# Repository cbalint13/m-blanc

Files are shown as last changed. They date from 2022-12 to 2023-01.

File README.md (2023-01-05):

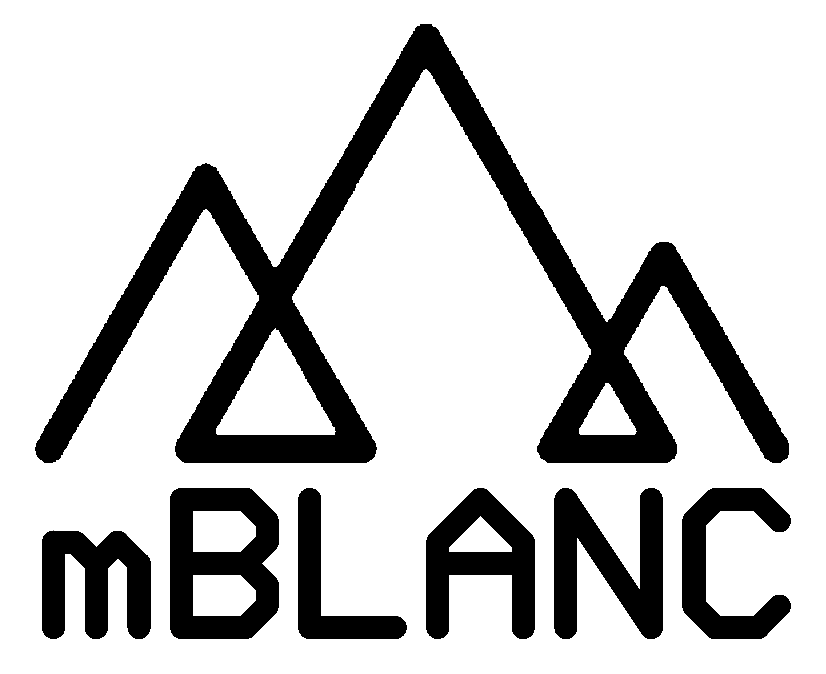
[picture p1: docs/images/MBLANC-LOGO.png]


**m**ini **B**oard **La**b a**n**d **C**ompanion

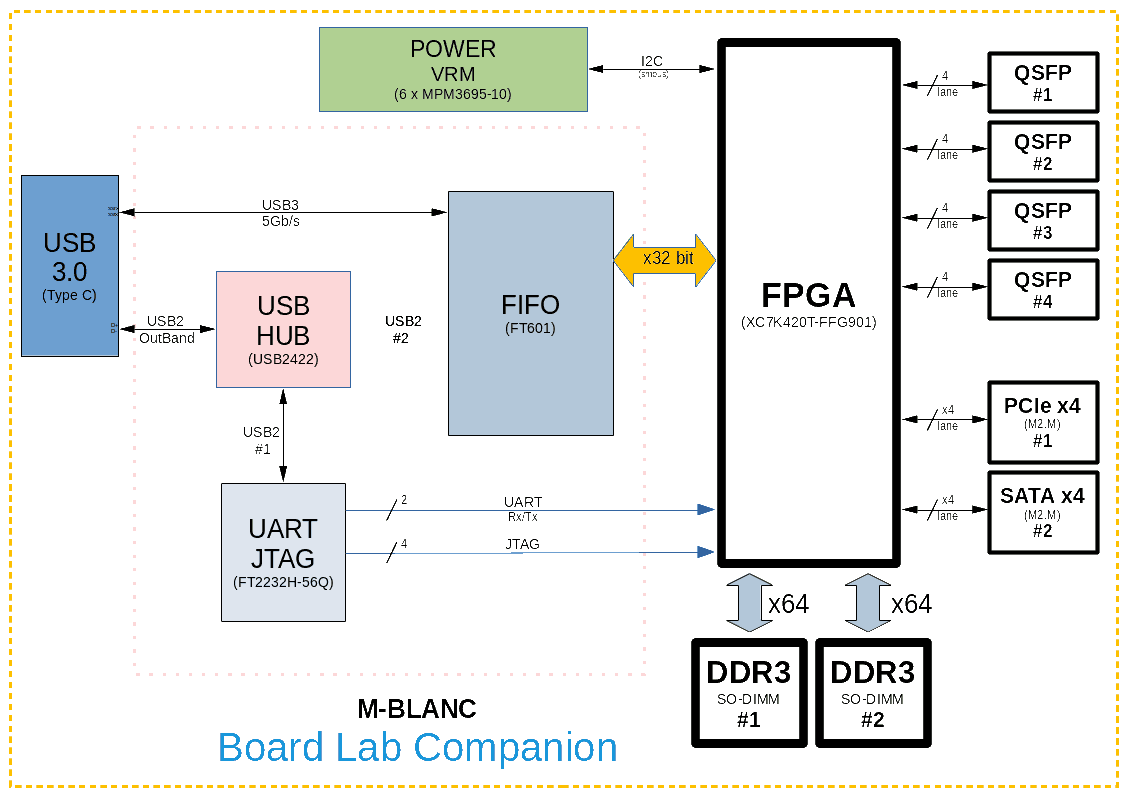
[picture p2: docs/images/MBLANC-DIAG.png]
DIAG


## Description

  With the rising of high quality opensource tools for FPGAs new opportunities are emerging to discover and build better digital architectures.
  This board is intended to explore & research the world of modern digital systems that requires large memory bus and high-speed peripherials.

## Specs:

* Large **xc7k420t** **FPGA** design space
* Two **DDR3 SO-DIMM** sockets having **128 (2 x 64) bits** wide access
* USB3 **5Gbps/s** data access over **x32** wide independent FIFO
* USB2 outband (same usb port) permanent **JTAG** and **UART** independent access
* Two  **M.2** (M-key), 4 x SERDes lanes each, PCIe & SATA mappable
* Four **QSFP** sockets 4 x SERDes lanes each, with up to 10Gb/s line rates

Can be used in any USB port right from the tips of fingers, no cables, no wires but full control.

| TOP | BOTTOM |
| --- | --- |
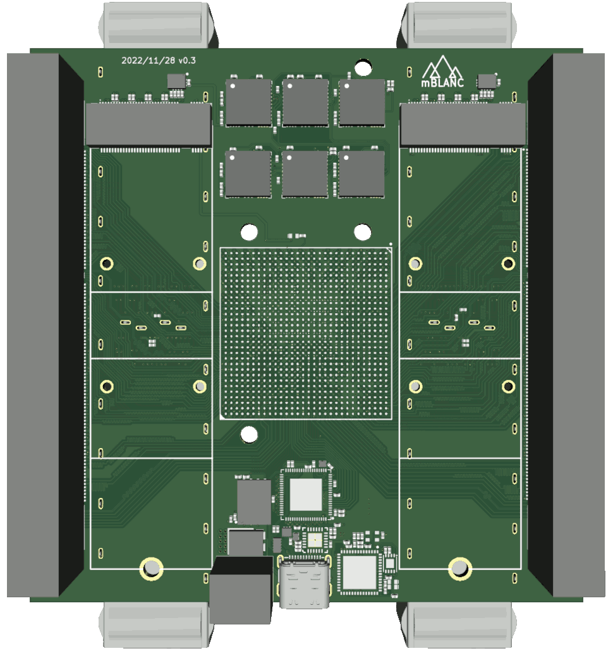
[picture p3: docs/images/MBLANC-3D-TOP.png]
TOP
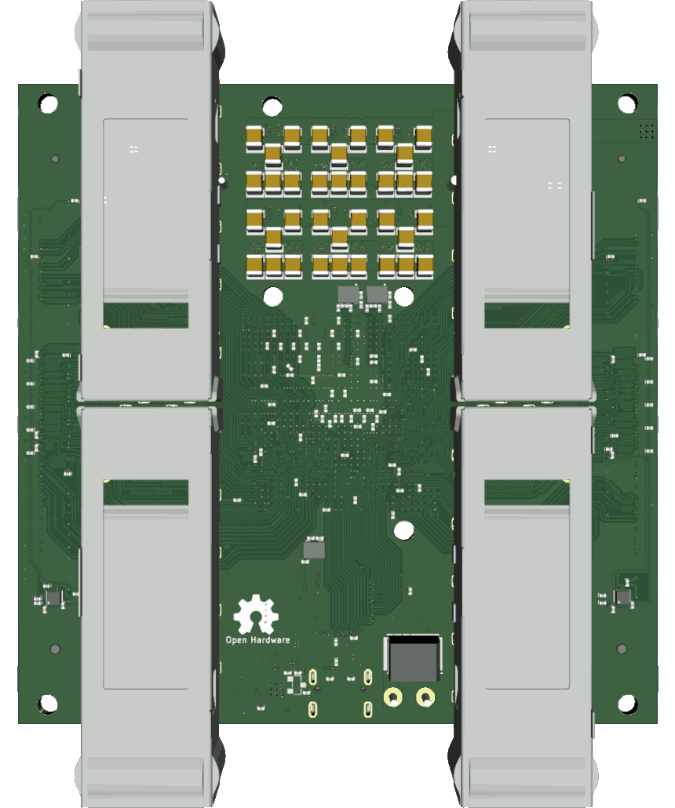
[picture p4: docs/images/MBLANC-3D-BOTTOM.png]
BOTTOM
|||

## Progress:

* ```17-Aug-2021``` Initial design and PCB prototype is done.
* ```22-Nov-2022``` Updated design having first PCB samples.

## Project files

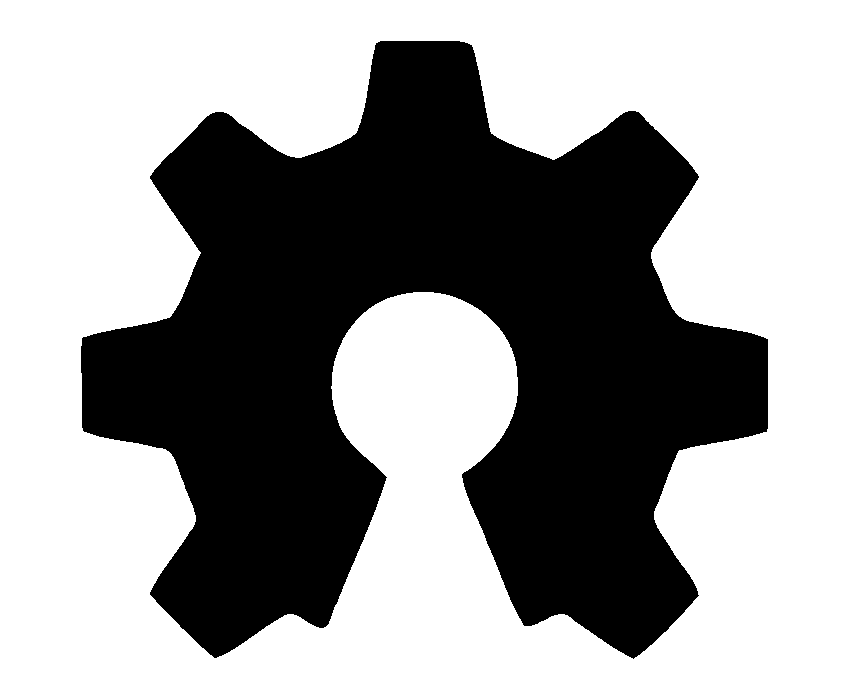
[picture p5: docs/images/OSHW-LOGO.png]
* Open Source Hardware 
* Check [schematic](hardware/m-BLANC-v0_3.pdf) available as quick readable document.
* See the [design files](hardware) available for Altium ®, CircuitMaker ®, KiCAD and Gerber format.

## PCB views

| Layer | Desc | Image | Layer | Desc | Image |
| --- | ---- | --- | --- | ---- | --- |
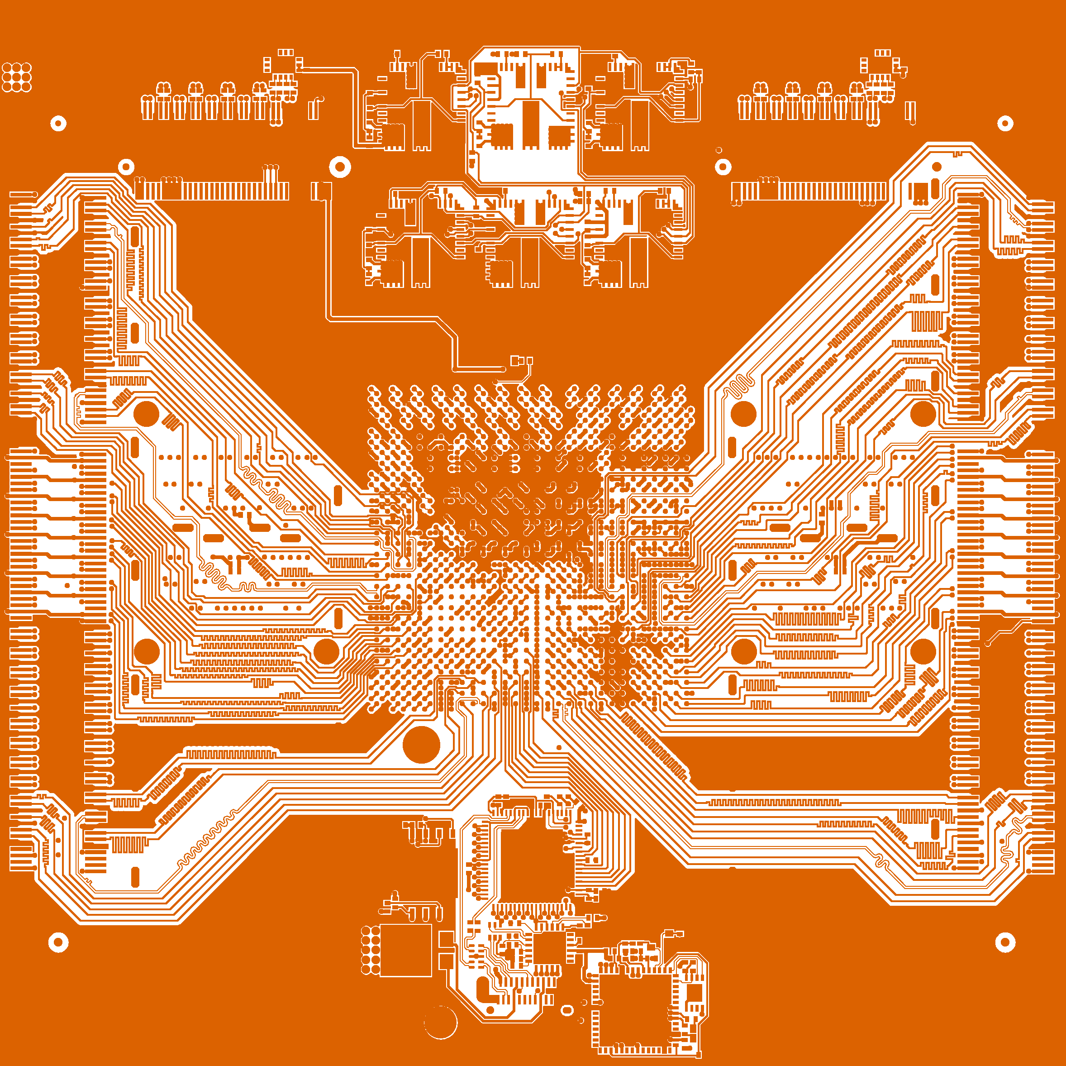
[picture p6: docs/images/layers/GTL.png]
GTL
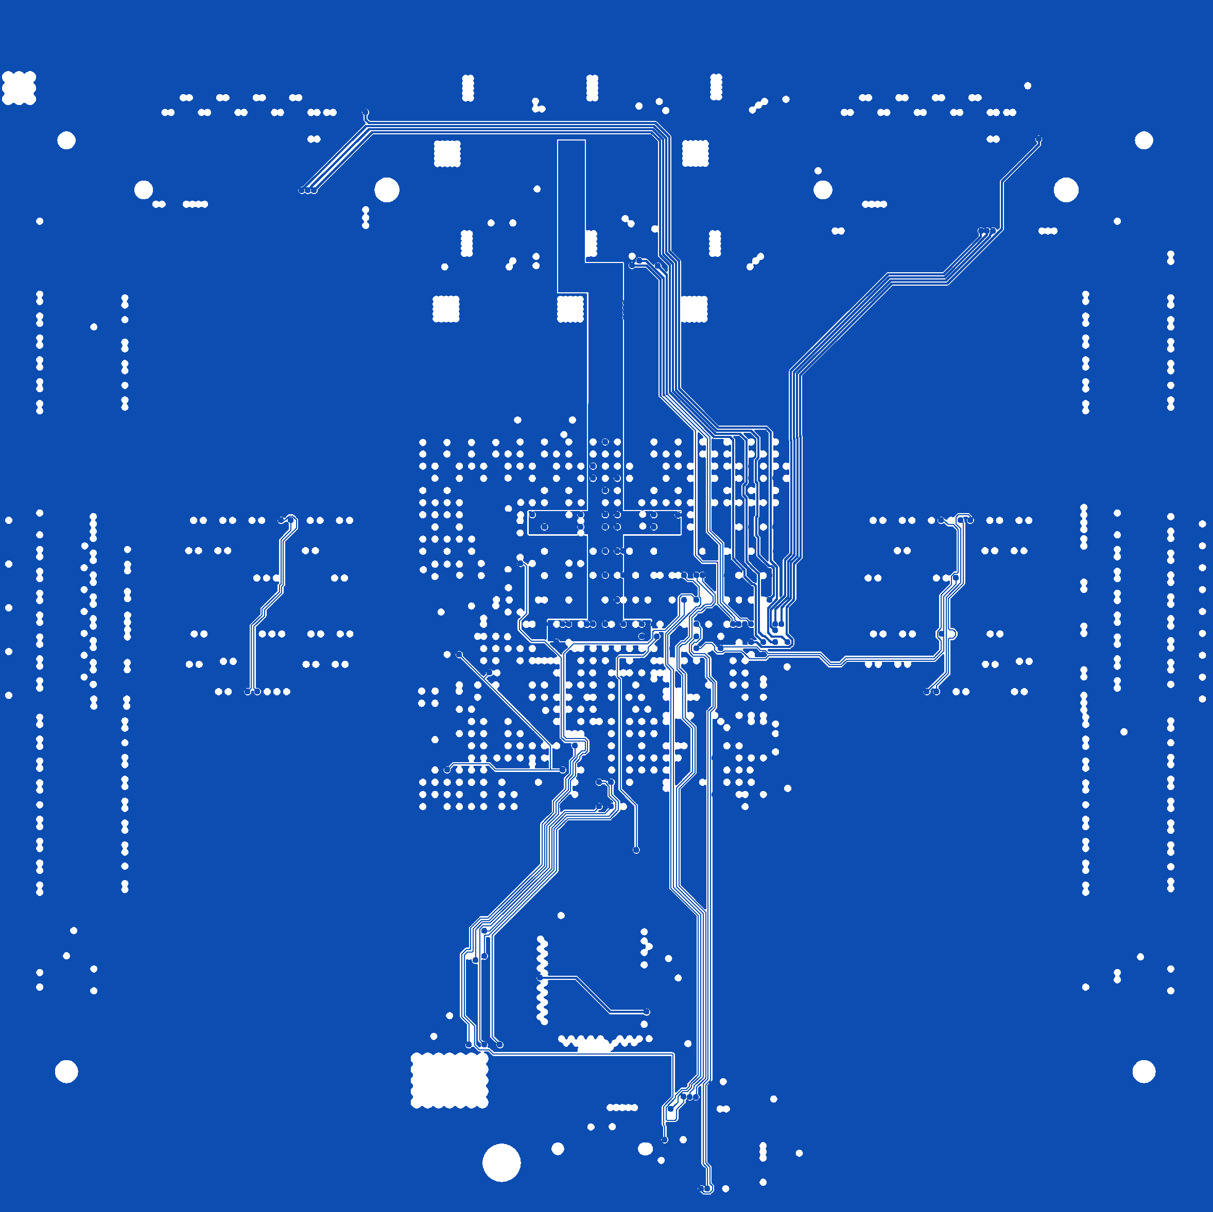
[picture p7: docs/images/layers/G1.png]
G1
|**Top** |Signal||**Inner1**|GND |  |
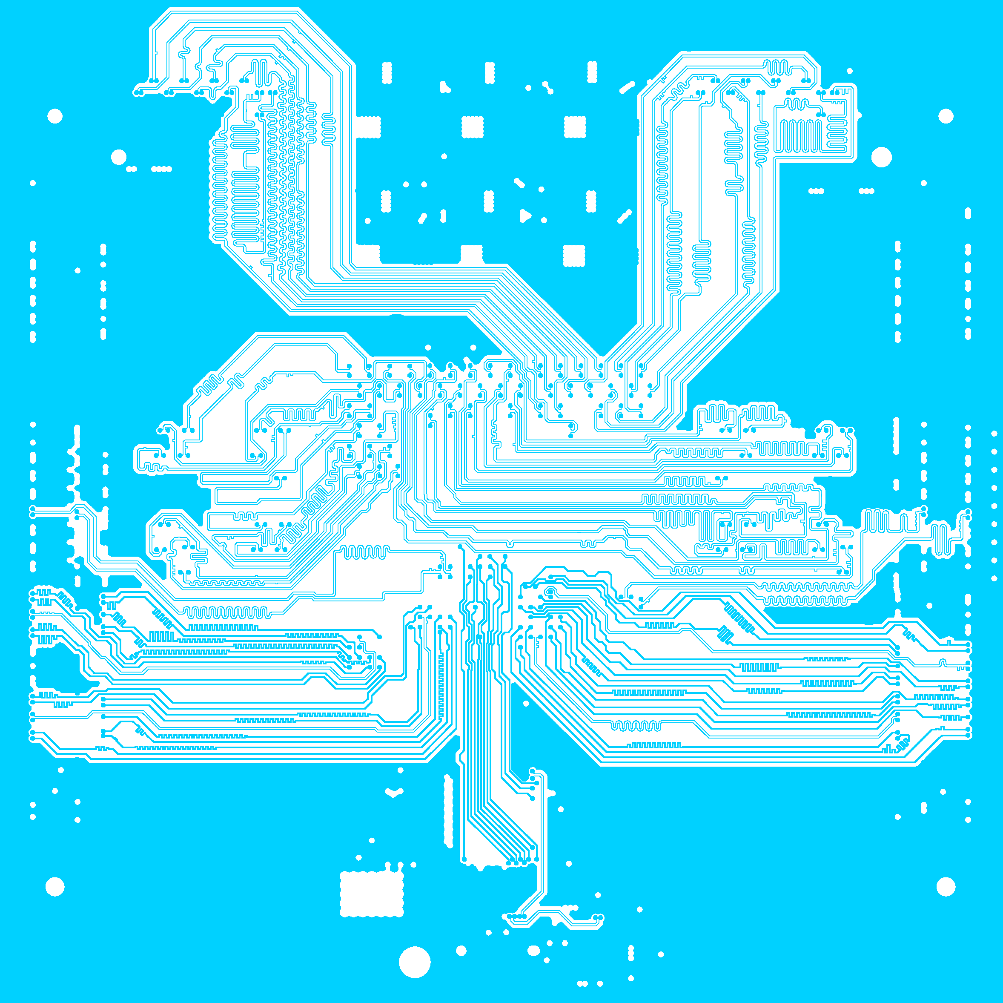
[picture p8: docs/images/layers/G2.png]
G2
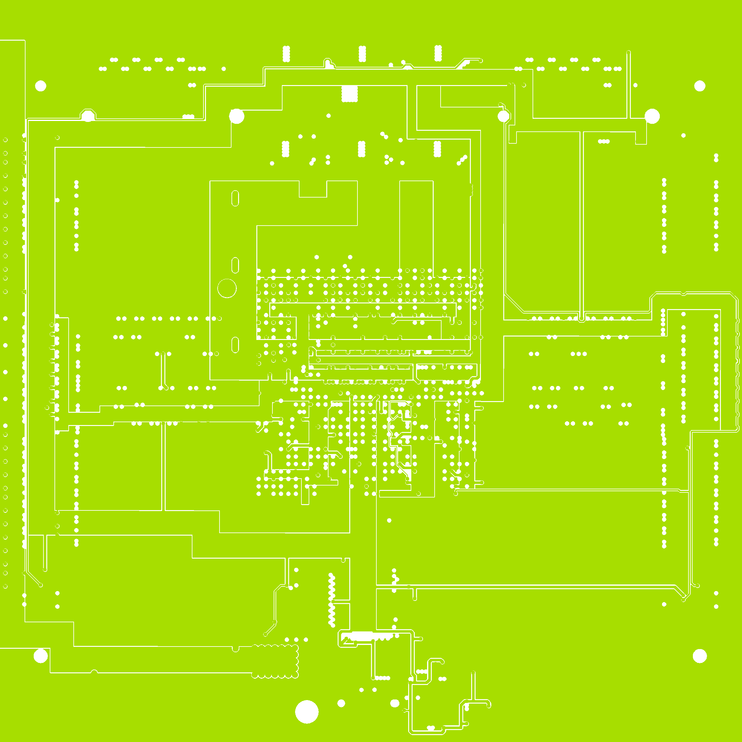
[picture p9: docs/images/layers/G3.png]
G3
|**Inner2**|Signal|  |**Inner3**|Power |  |
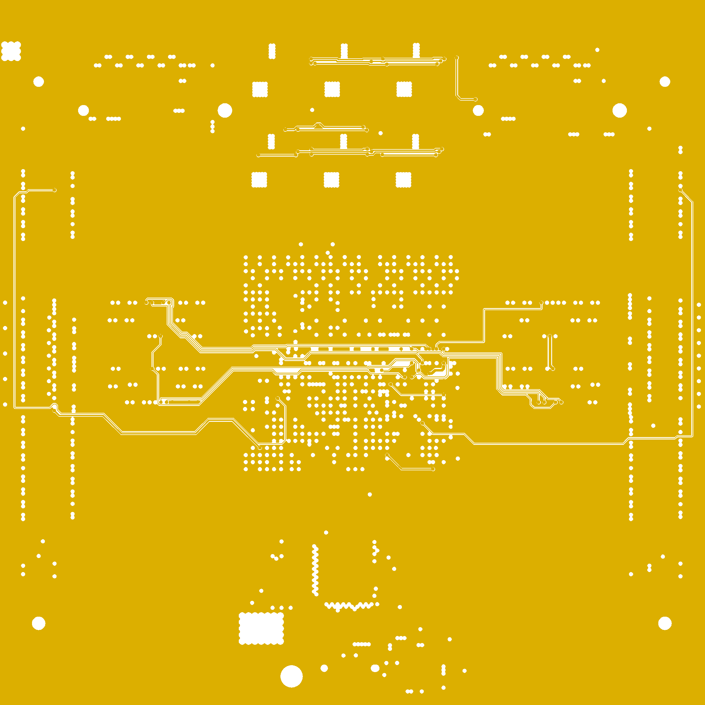
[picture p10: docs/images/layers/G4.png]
G4
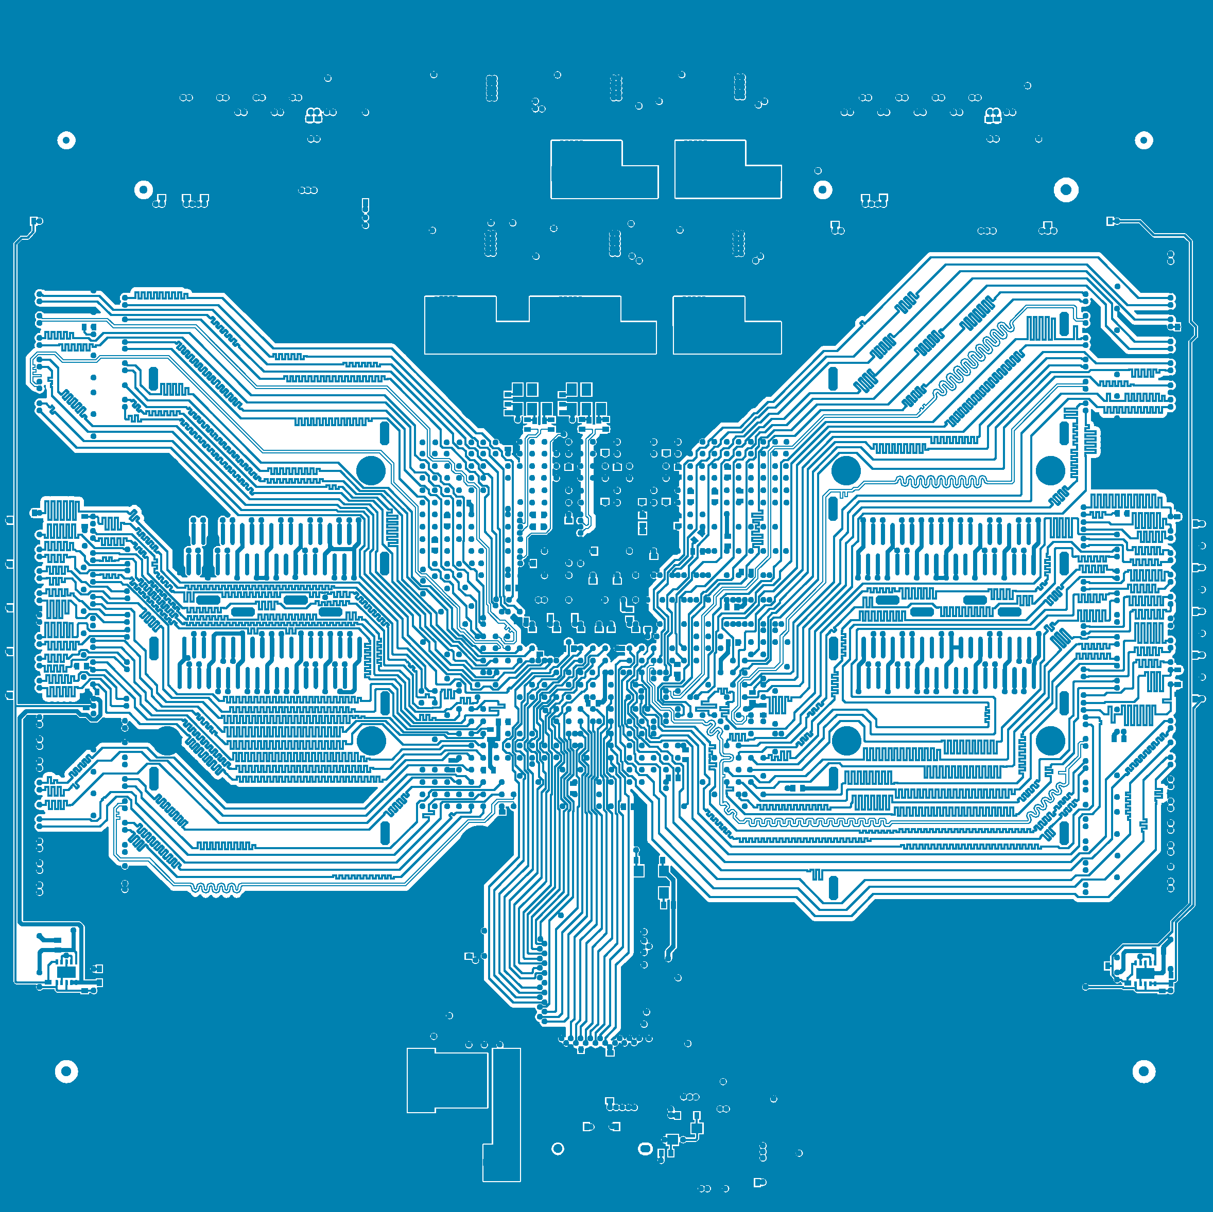
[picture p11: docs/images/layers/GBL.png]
GBL
|**Inner4**|GND |  |**Bottom**|Signal||

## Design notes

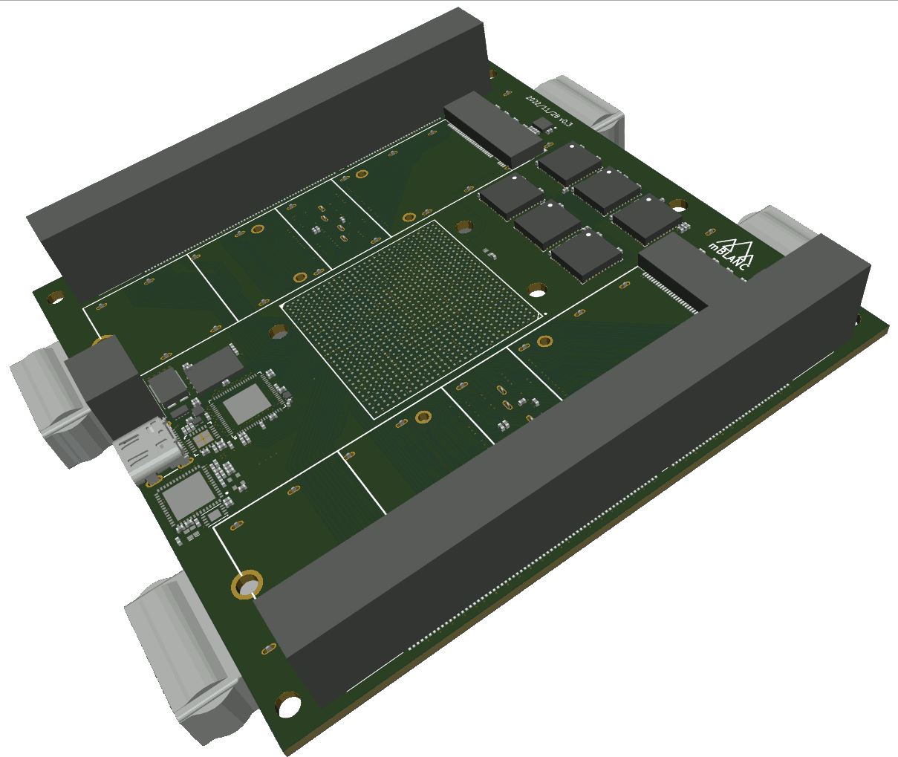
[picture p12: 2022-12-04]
docs/images/MBLANC-3D.png

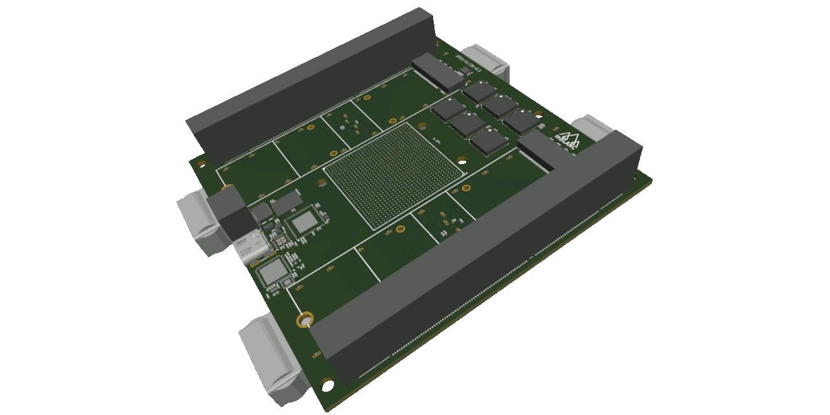
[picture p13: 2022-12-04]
docs/images/MBLANC-3D-preview.png

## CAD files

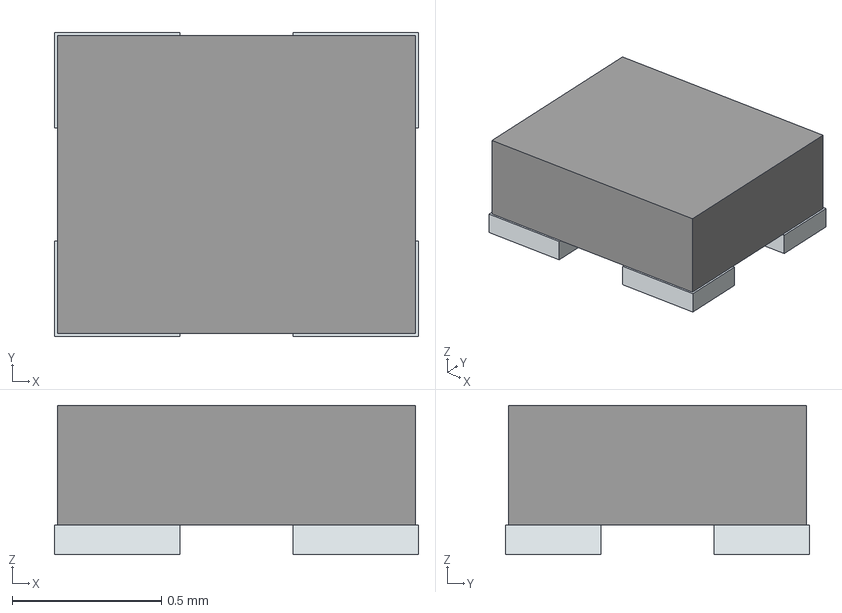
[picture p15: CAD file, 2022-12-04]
hardware/mblanc_v0.3/kicad/m-blanc/3d-models/ABM13W-52.0000MHZ-5-B2G-T5.stp
1.22 x 1.02 x 0.5 mm
('pin',_'1')
('pin',_'2')
('pin',_'3')
('pin',_'4')

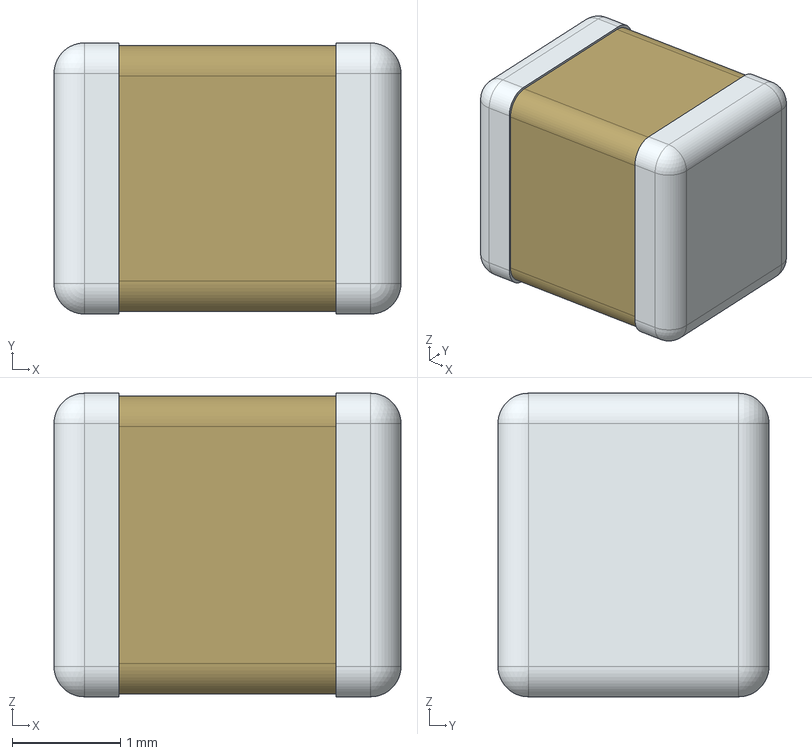
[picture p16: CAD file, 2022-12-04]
hardware/mblanc_v0.3/kicad/m-blanc/3d-models/JMK325ABJ107MM-P.stp
3.20 x 2.50 x 2.80 mm

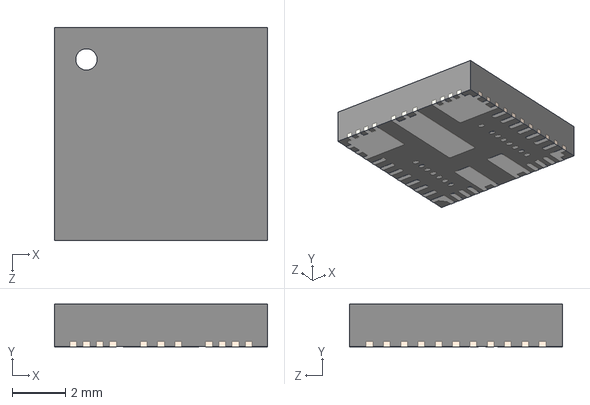
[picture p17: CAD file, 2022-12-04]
hardware/mblanc_v0.3/kicad/m-blanc/3d-models/MPM3695-10.STEP
8.00 x 1.61 x 8.00 mm

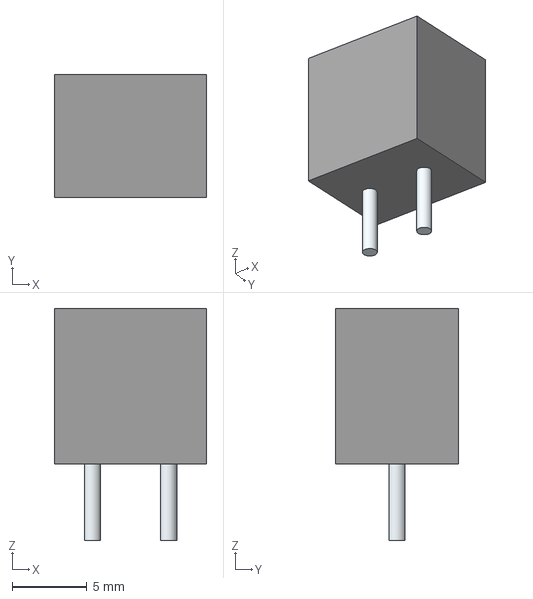
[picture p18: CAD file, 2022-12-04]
hardware/mblanc_v0.3/kicad/m-blanc/3d-models/TB006-508-02BE.stp
10.2 x 8.20 x 15.5 mm
Leads x 2

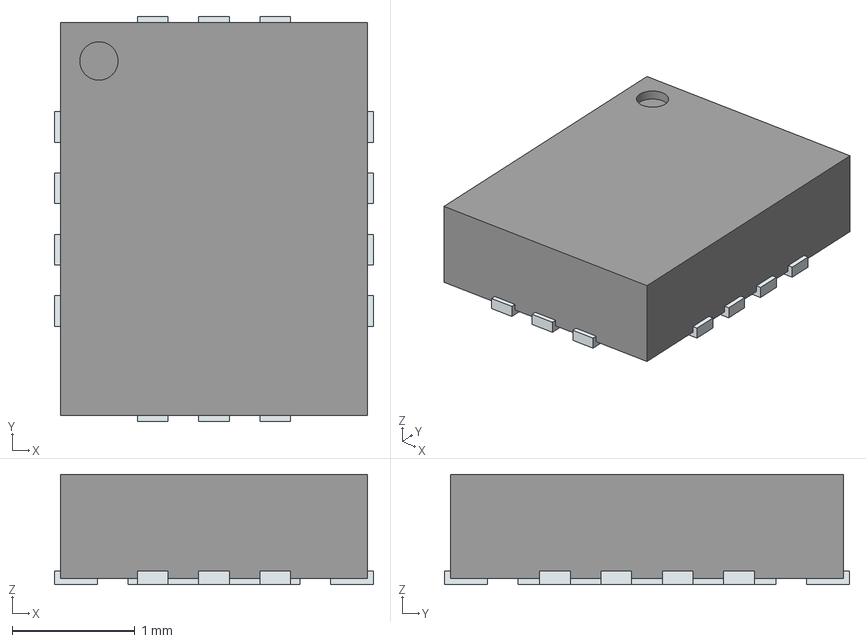
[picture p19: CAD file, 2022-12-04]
hardware/mblanc_v0.3/kicad/m-blanc/3d-models/DSC557-0344FI0.stp
2.60 x 3.30 x 0.9 mm
ThermalPin
PinsArrayLR
PinsArrayTB

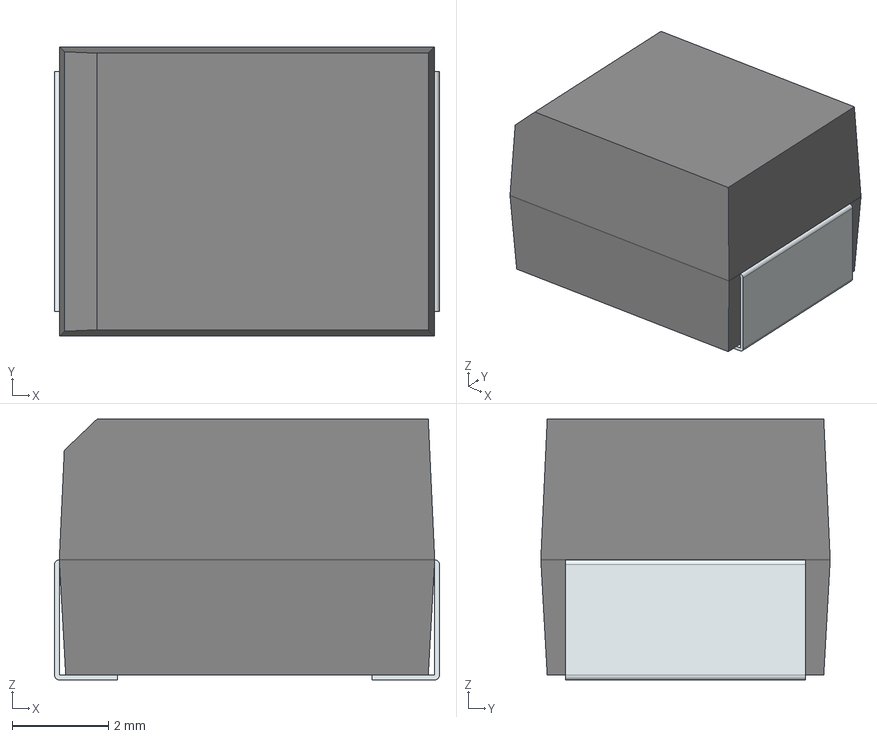
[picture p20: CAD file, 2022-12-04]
hardware/mblanc_v0.3/kicad/m-blanc/3d-models/SK106-TP.stp
8.02 x 6.03 x 5.43 mm
FilletPin1
FilletPin2

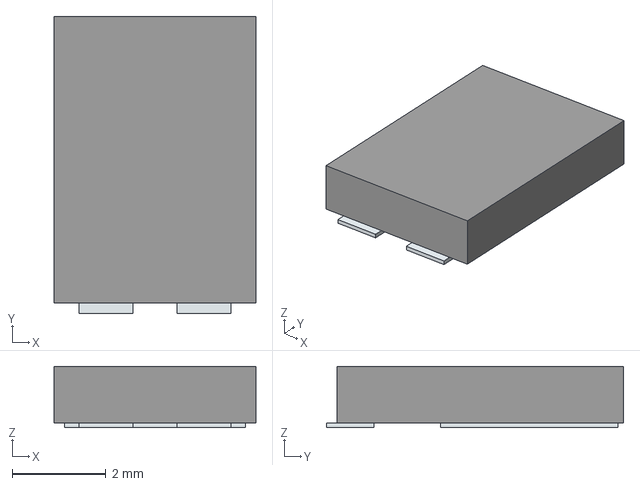
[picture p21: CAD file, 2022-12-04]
hardware/mblanc_v0.3/kicad/m-blanc/3d-models/V10P20-M3_86A.stp
4.30 x 6.32 x 1.30 mm
Pins

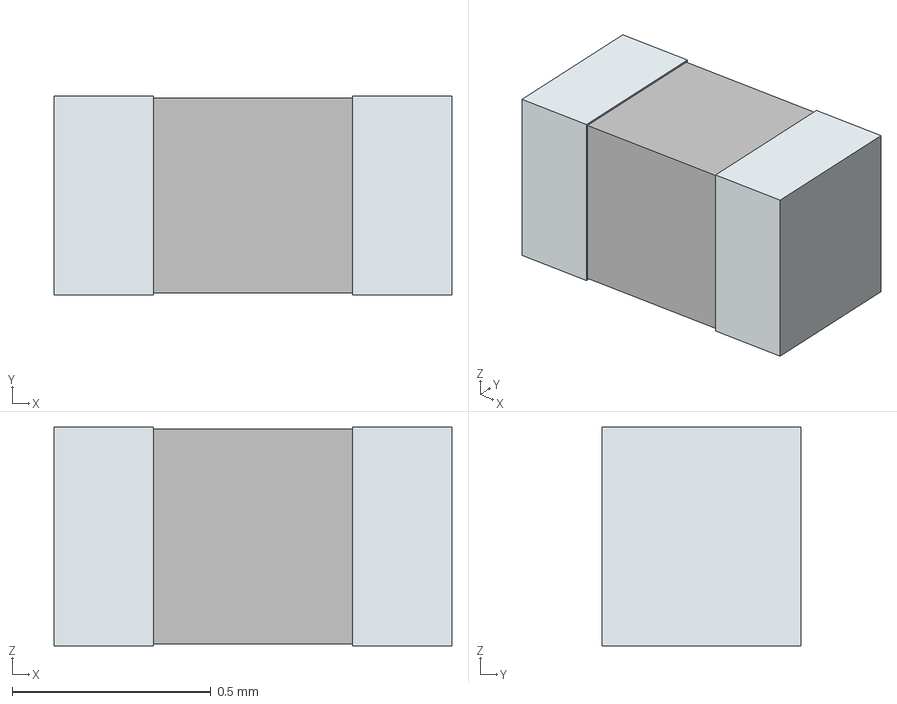
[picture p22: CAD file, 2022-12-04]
hardware/mblanc_v0.3/kicad/m-blanc/3d-models/BLM15AX601SN1D.stp
1.00 x 0.5 x 0.55 mm
term1
term2

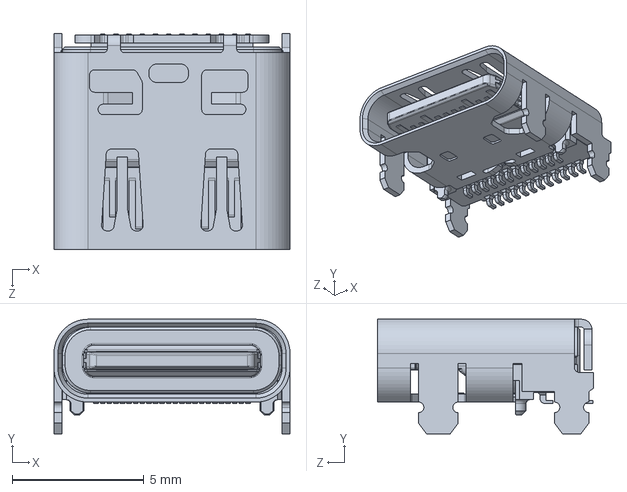
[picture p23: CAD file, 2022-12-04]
hardware/mblanc_v0.3/kicad/m-blanc/3d-models/K3D-DX07S024JA2-V1_JAE_Proprietary.STEP
8.94 x 4.34 x 8.17 mm

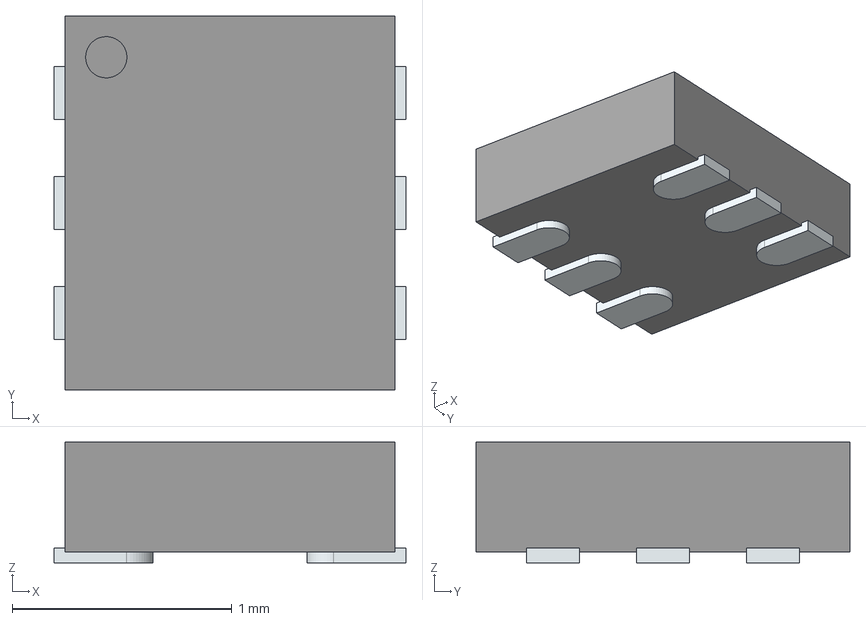
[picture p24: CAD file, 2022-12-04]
hardware/mblanc_v0.3/kicad/m-blanc/3d-models/ECMF02-2AMX6.stp
1.60 x 1.70 x 0.55 mm
PinsArrayLR

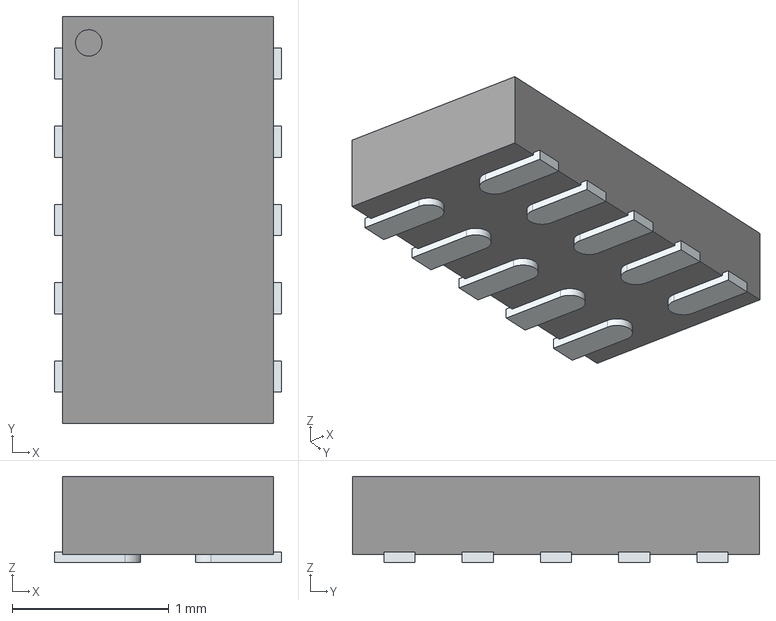
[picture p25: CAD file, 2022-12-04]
hardware/mblanc_v0.3/kicad/m-blanc/3d-models/ECMF04-4HSWM10.stp
1.45 x 2.60 x 0.55 mm
PinsArrayLR

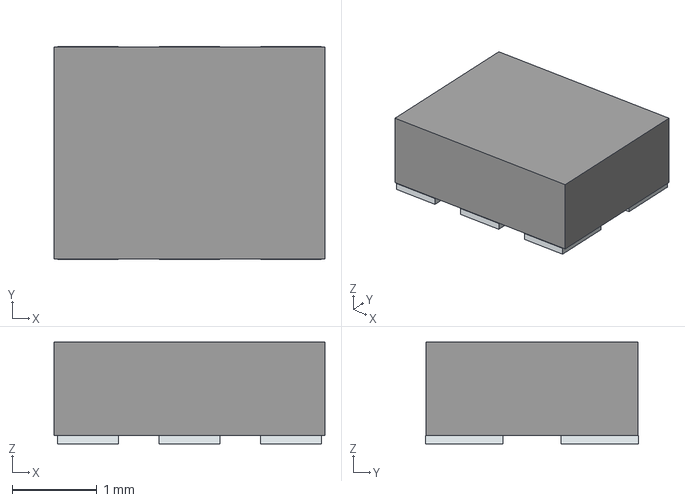
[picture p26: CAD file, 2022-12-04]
hardware/mblanc_v0.3/kicad/m-blanc/3d-models/AX3DAF1-100.0000.stp
3.20 x 2.52 x 1.20 mm
Pins

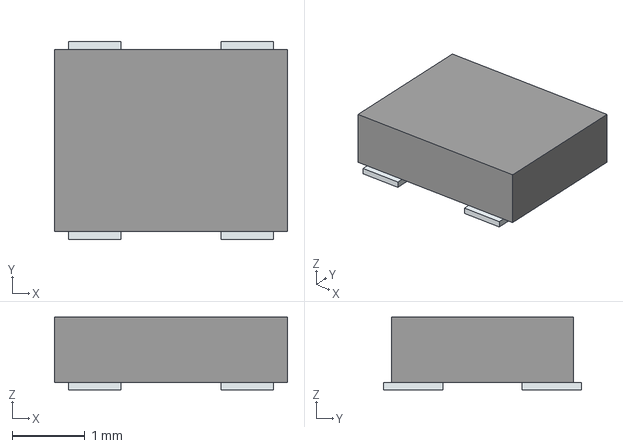
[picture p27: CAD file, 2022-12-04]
hardware/mblanc_v0.3/kicad/m-blanc/3d-models/ASEM1-100.000MHZ-L-C-T.stp
3.20 x 2.72 x 1.00 mm
Pins

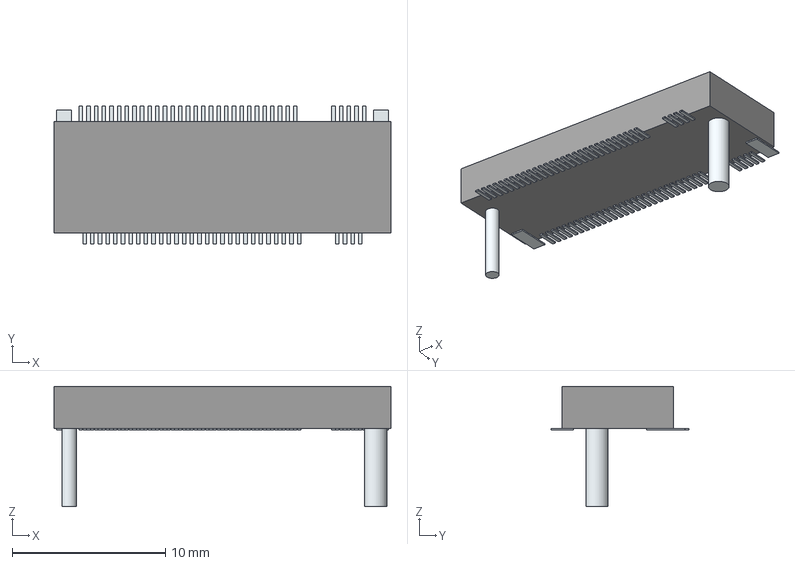
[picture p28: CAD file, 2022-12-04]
hardware/mblanc_v0.3/kicad/m-blanc/3d-models/MDT275M02001.stp
22.0 x 9.04 x 7.85 mm
('pin',_'1')
('pin',_'2')
('pin',_'3')
('pin',_'4')
('pin',_'5')
('pin',_'6')
('pin',_'7')
('pin',_'8')
('pin',_'9')
('pin',_'10')
('pin',_'11')
('pin',_'12')
('pin',_'13')
('pin',_'14')
('pin',_'15')
('pin',_'16')
('pin',_'17')
('pin',_'18')
('pin',_'19')
('pin',_'20')
('pin',_'21')
('pin',_'22')
('pin',_'23')
('pin',_'24')
('pin',_'25')
('pin',_'26')
('pin',_'27')
('pin',_'28')
('pin',_'29')
('pin',_'30')
('pin',_'31')
('pin',_'32')
('pin',_'33')
('pin',_'34')
('pin',_'35')
('pin',_'36')
('pin',_'37')
('pin',_'38')
('pin',_'39')
('pin',_'40')
('pin',_'41')
('pin',_'42')
('pin',_'43')
('pin',_'44')
('pin',_'45')
('pin',_'46')
('pin',_'47')
('pin',_'48')
('pin',_'49')
('pin',_'50')
('pin',_'51')
('pin',_'52')
('pin',_'53')
('pin',_'54')
('pin',_'55')
('pin',_'56')
('pin',_'57')
('pin',_'58')
('pin',_'59')
('pin',_'60')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

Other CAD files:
hardware/mblanc_v0.3/kicad/m-blanc/3d-models/S25HL512TFANHI010.stp
hardware/mblanc_v0.3/kicad/m-blanc/3d-models/step_temp.STEP
hardware/mblanc_v0.3/kicad/m-blanc/3d-models/74750-0021.stp
hardware/mblanc_v0.3/kicad/m-blanc/3d-models/296409204003856+.stp

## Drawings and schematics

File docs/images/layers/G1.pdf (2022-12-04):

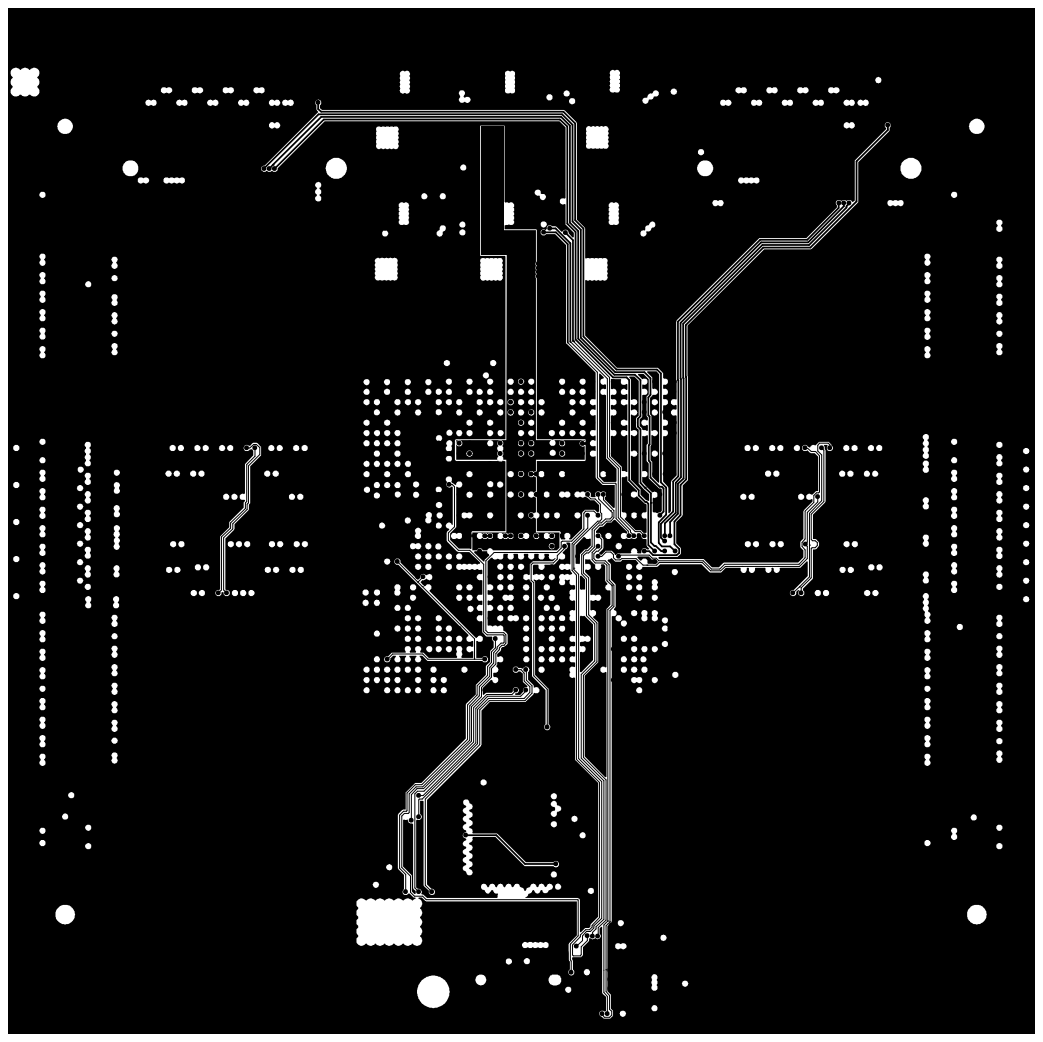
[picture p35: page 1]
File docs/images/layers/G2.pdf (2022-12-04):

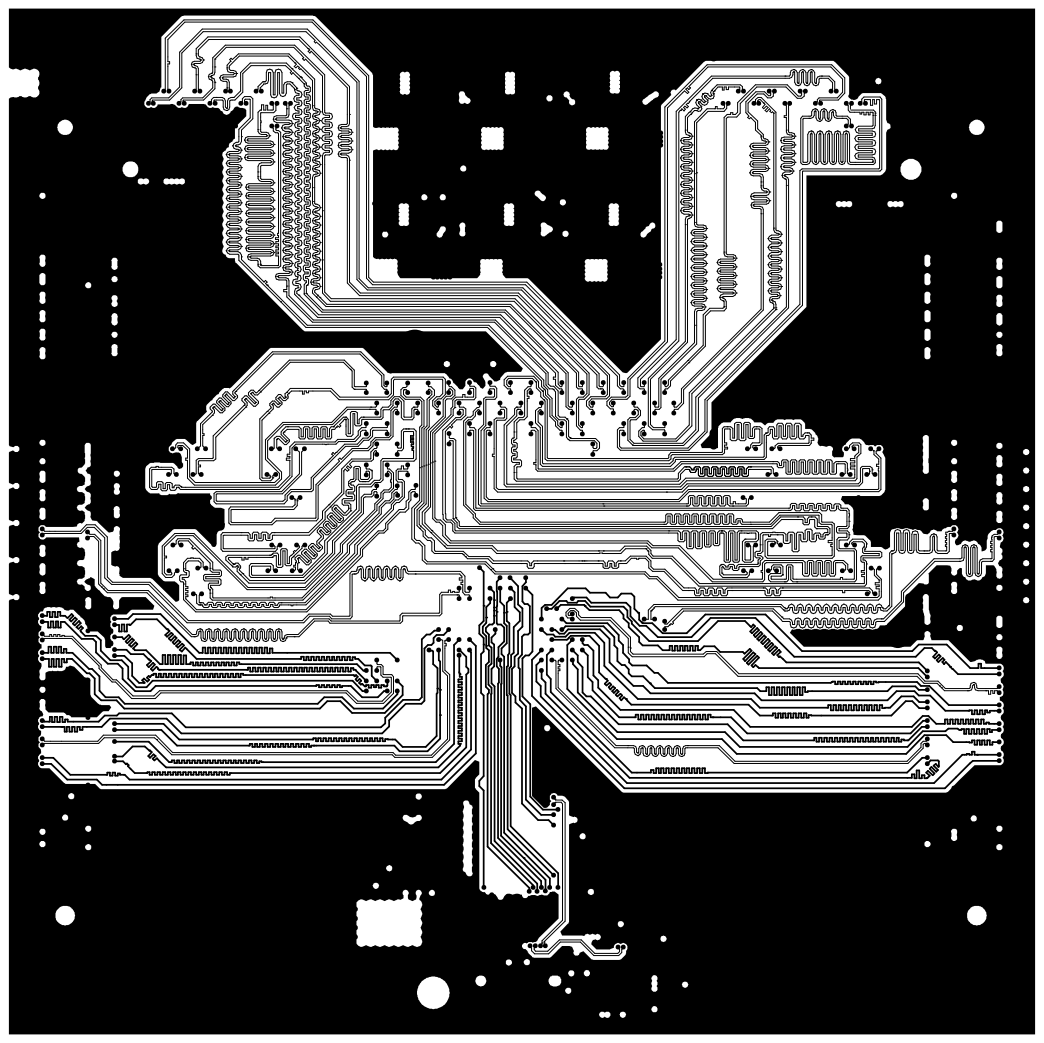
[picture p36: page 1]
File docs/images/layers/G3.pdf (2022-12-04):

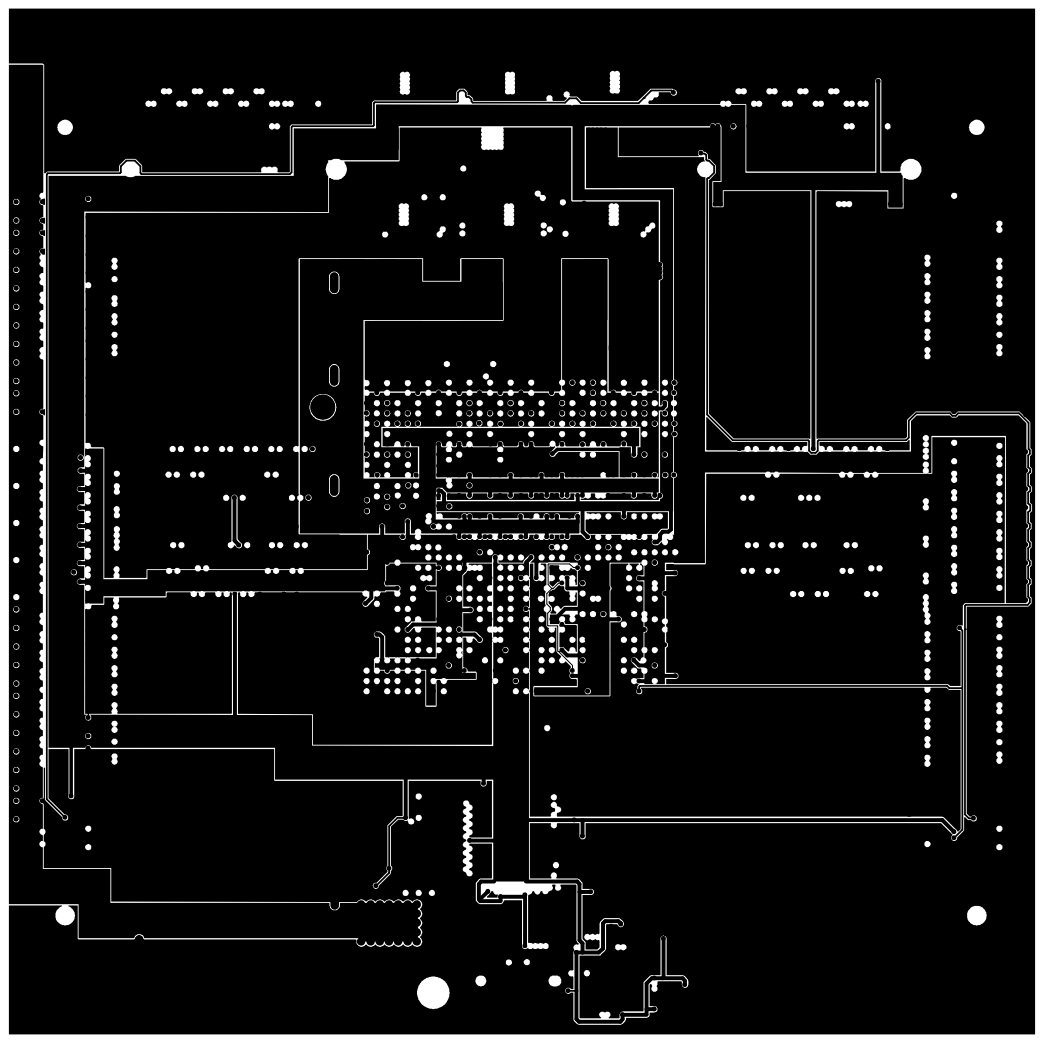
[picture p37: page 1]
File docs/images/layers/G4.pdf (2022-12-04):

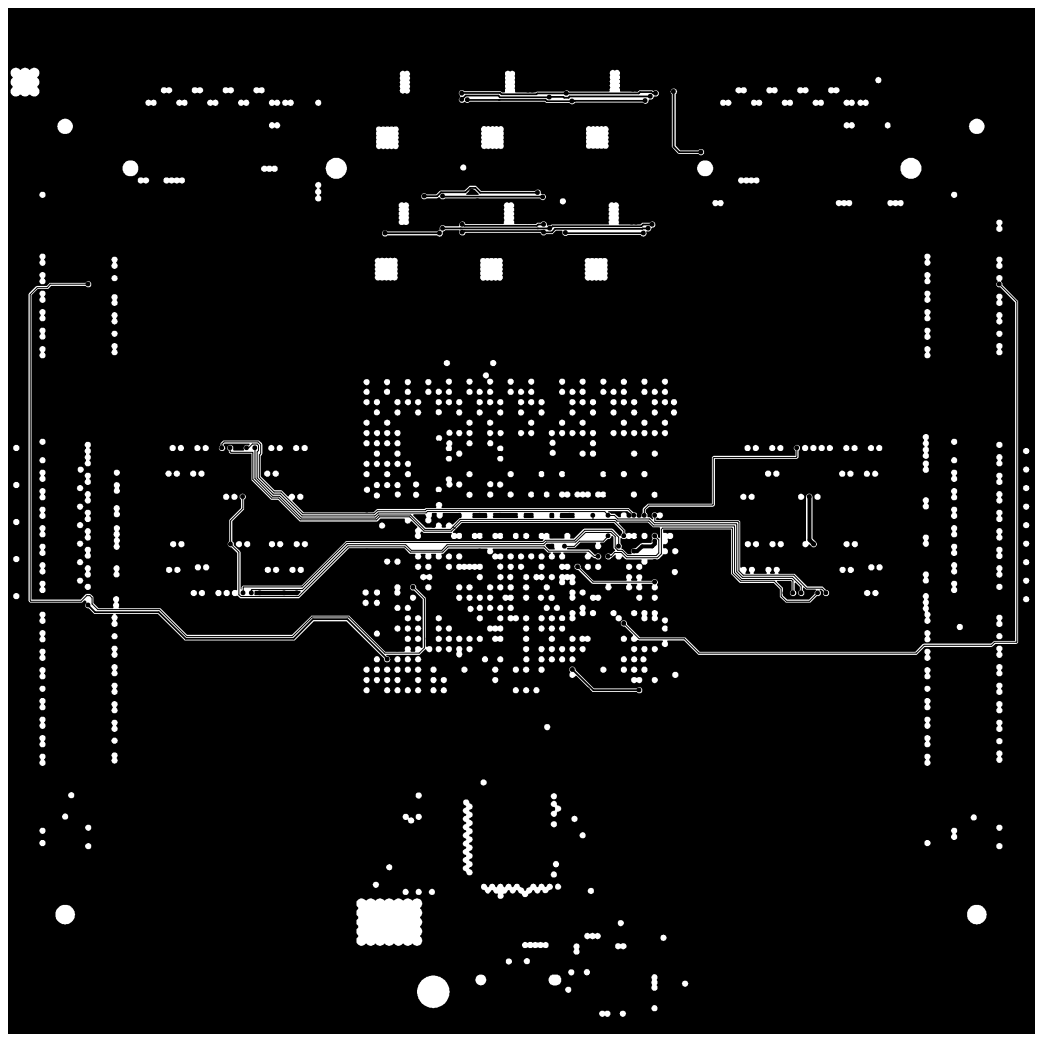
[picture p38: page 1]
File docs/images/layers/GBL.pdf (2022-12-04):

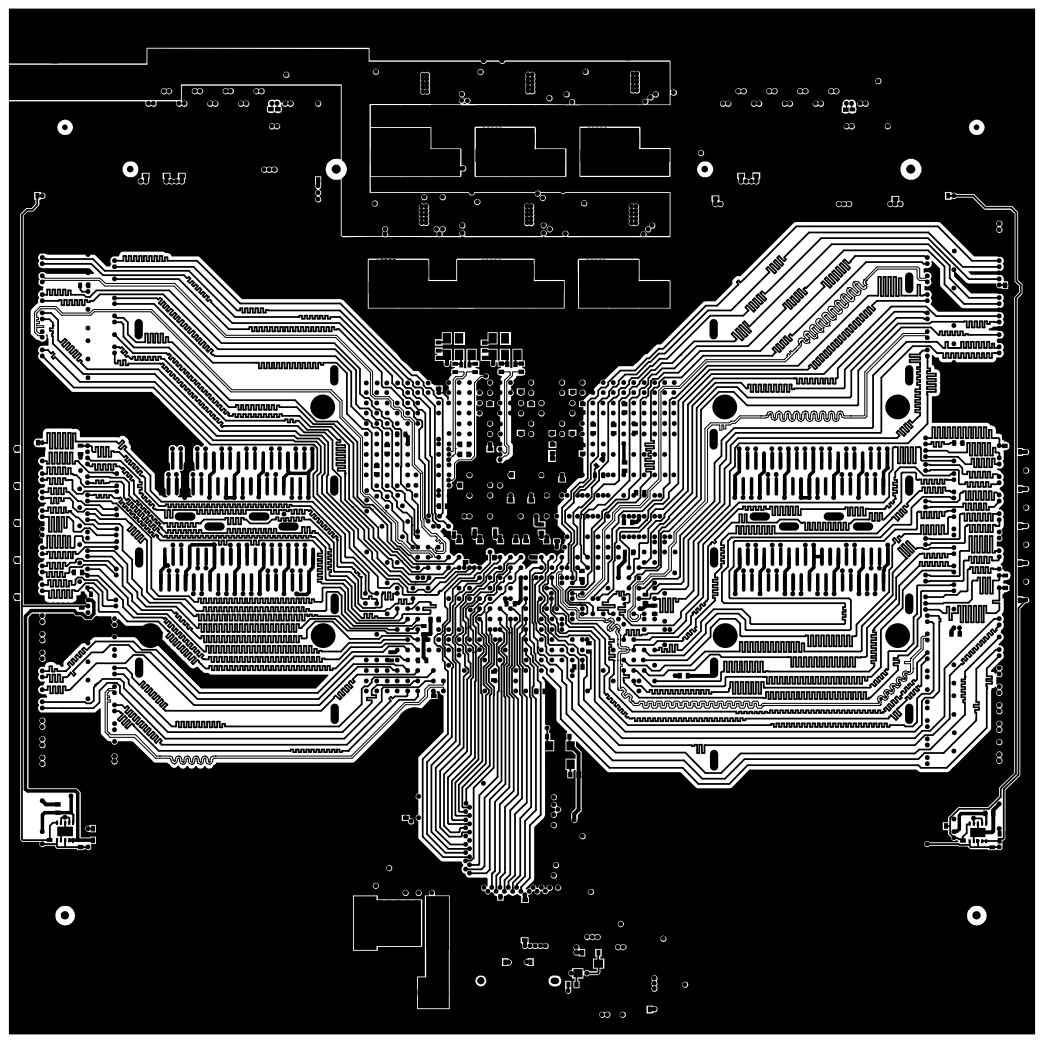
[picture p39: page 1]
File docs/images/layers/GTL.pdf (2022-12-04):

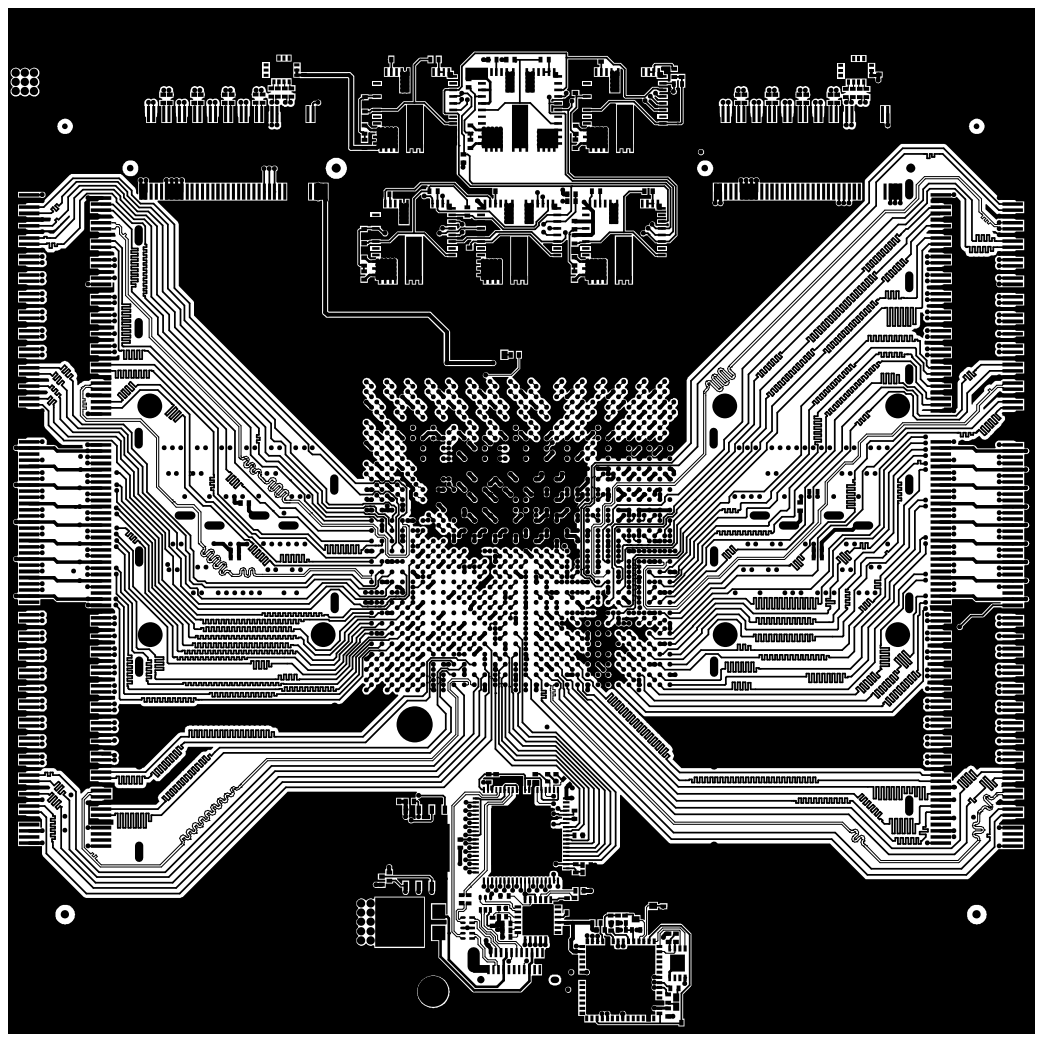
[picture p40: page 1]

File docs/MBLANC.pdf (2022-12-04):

## QSFP

## QSFP

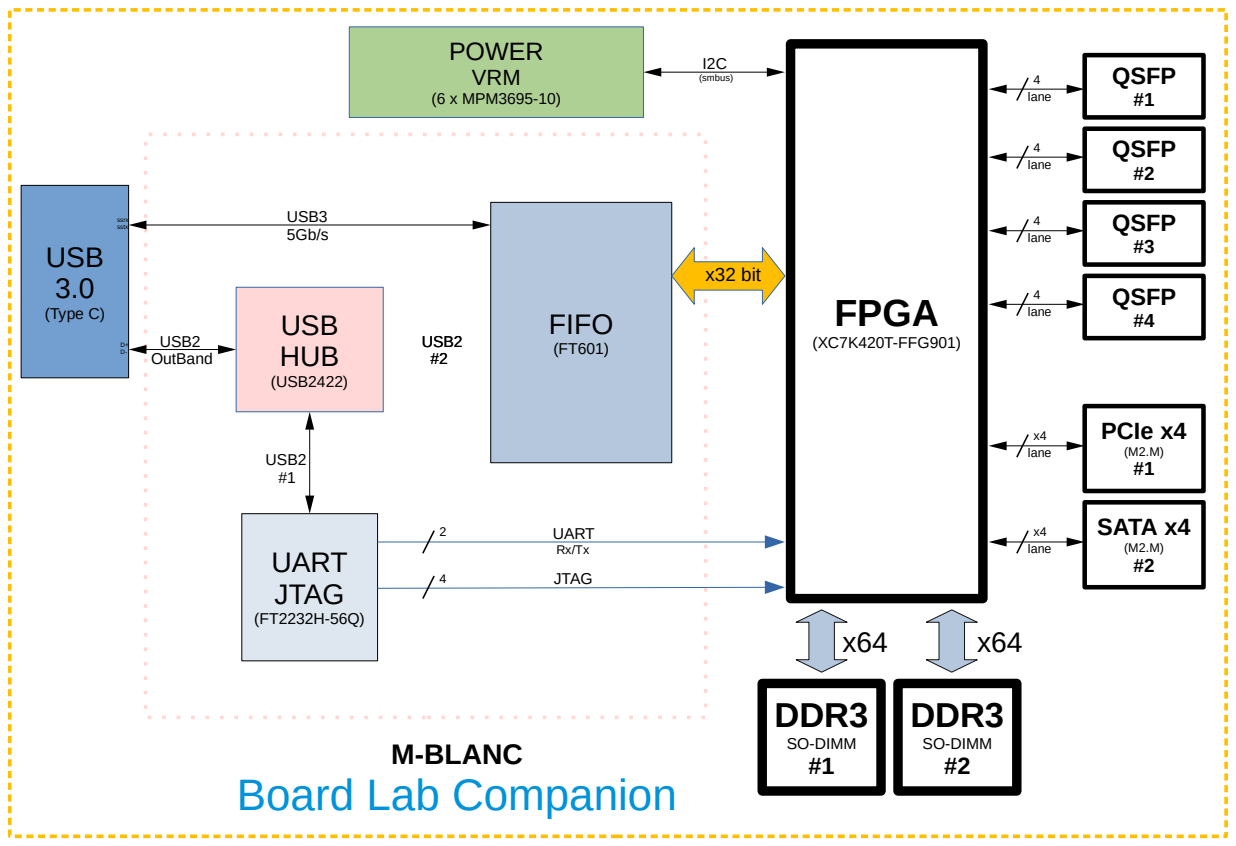
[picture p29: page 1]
USB; (Type C); HUB; (USB2422); FIFO; FPGA; (XC7K420T-FFG901); UART; JTAG; USB3; USB2; OutBand; x32 bit; ssrx sstx; M-BLANC; DDR3; SO-DIMM #1; SO-DIMM #2; PCIe x4; QSFP; SATA x4; lane; POWER; VRM; (6 x MPM3695-10); (smbus)

Board Lab Companion

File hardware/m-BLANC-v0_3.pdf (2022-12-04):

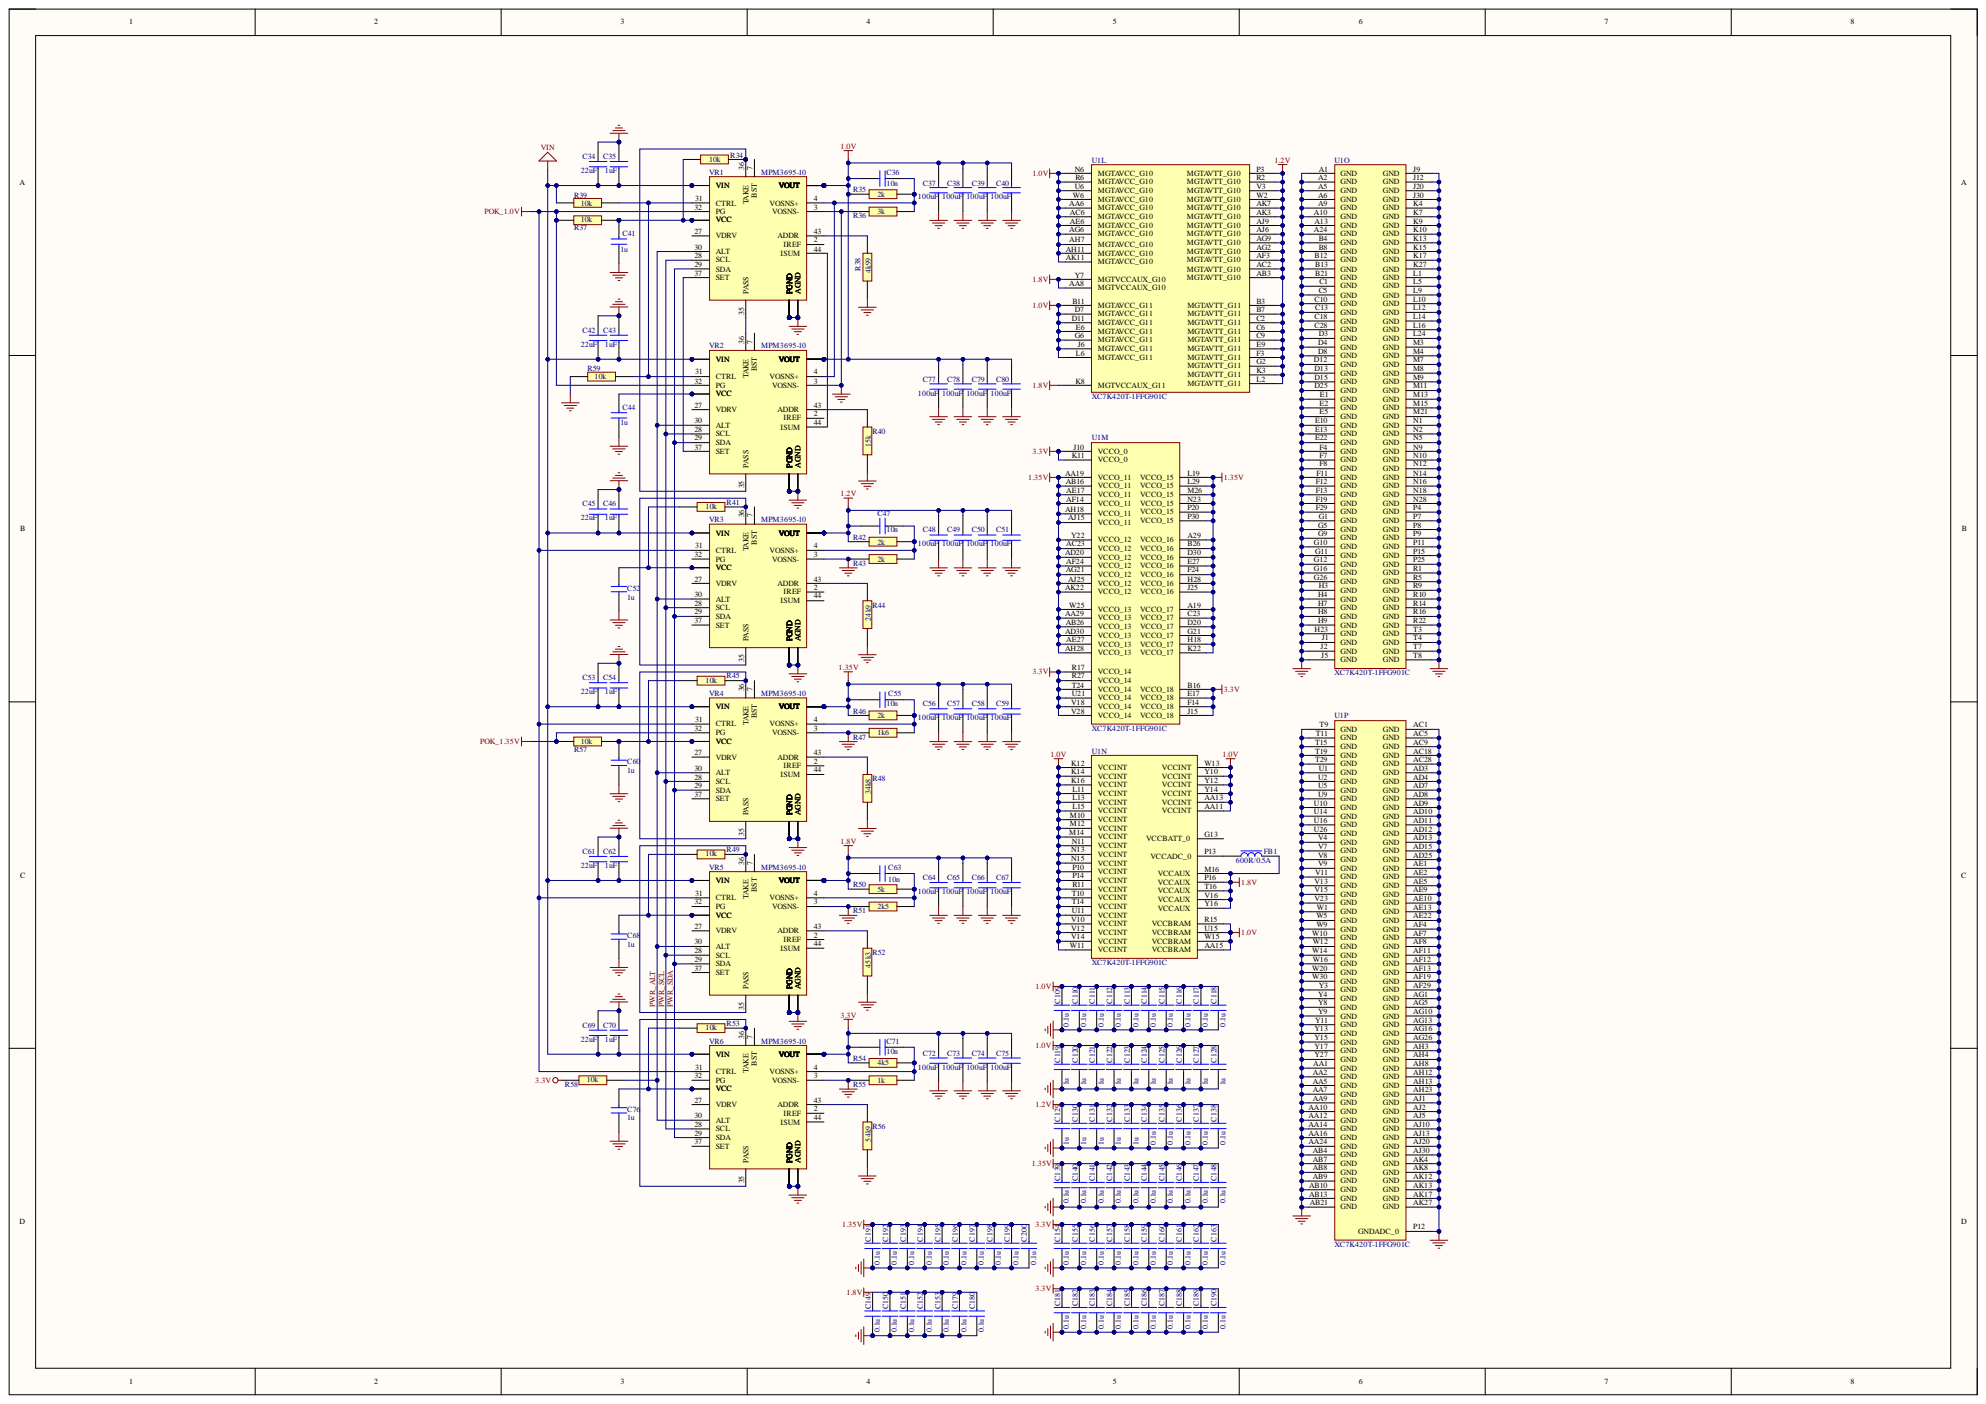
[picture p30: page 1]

2 7
3 0 | 2

2 9
3 7

V V I I N N CTR L P G V V C C C C V D RV ALT S C L S D A SET | V V V V V O O O O O U U U U U T TAGND T T TAGND V O S N S + V O S N S -A D D R I REF I S UM | 4 | 1 0 n
3 1 | | | R 5

2 8

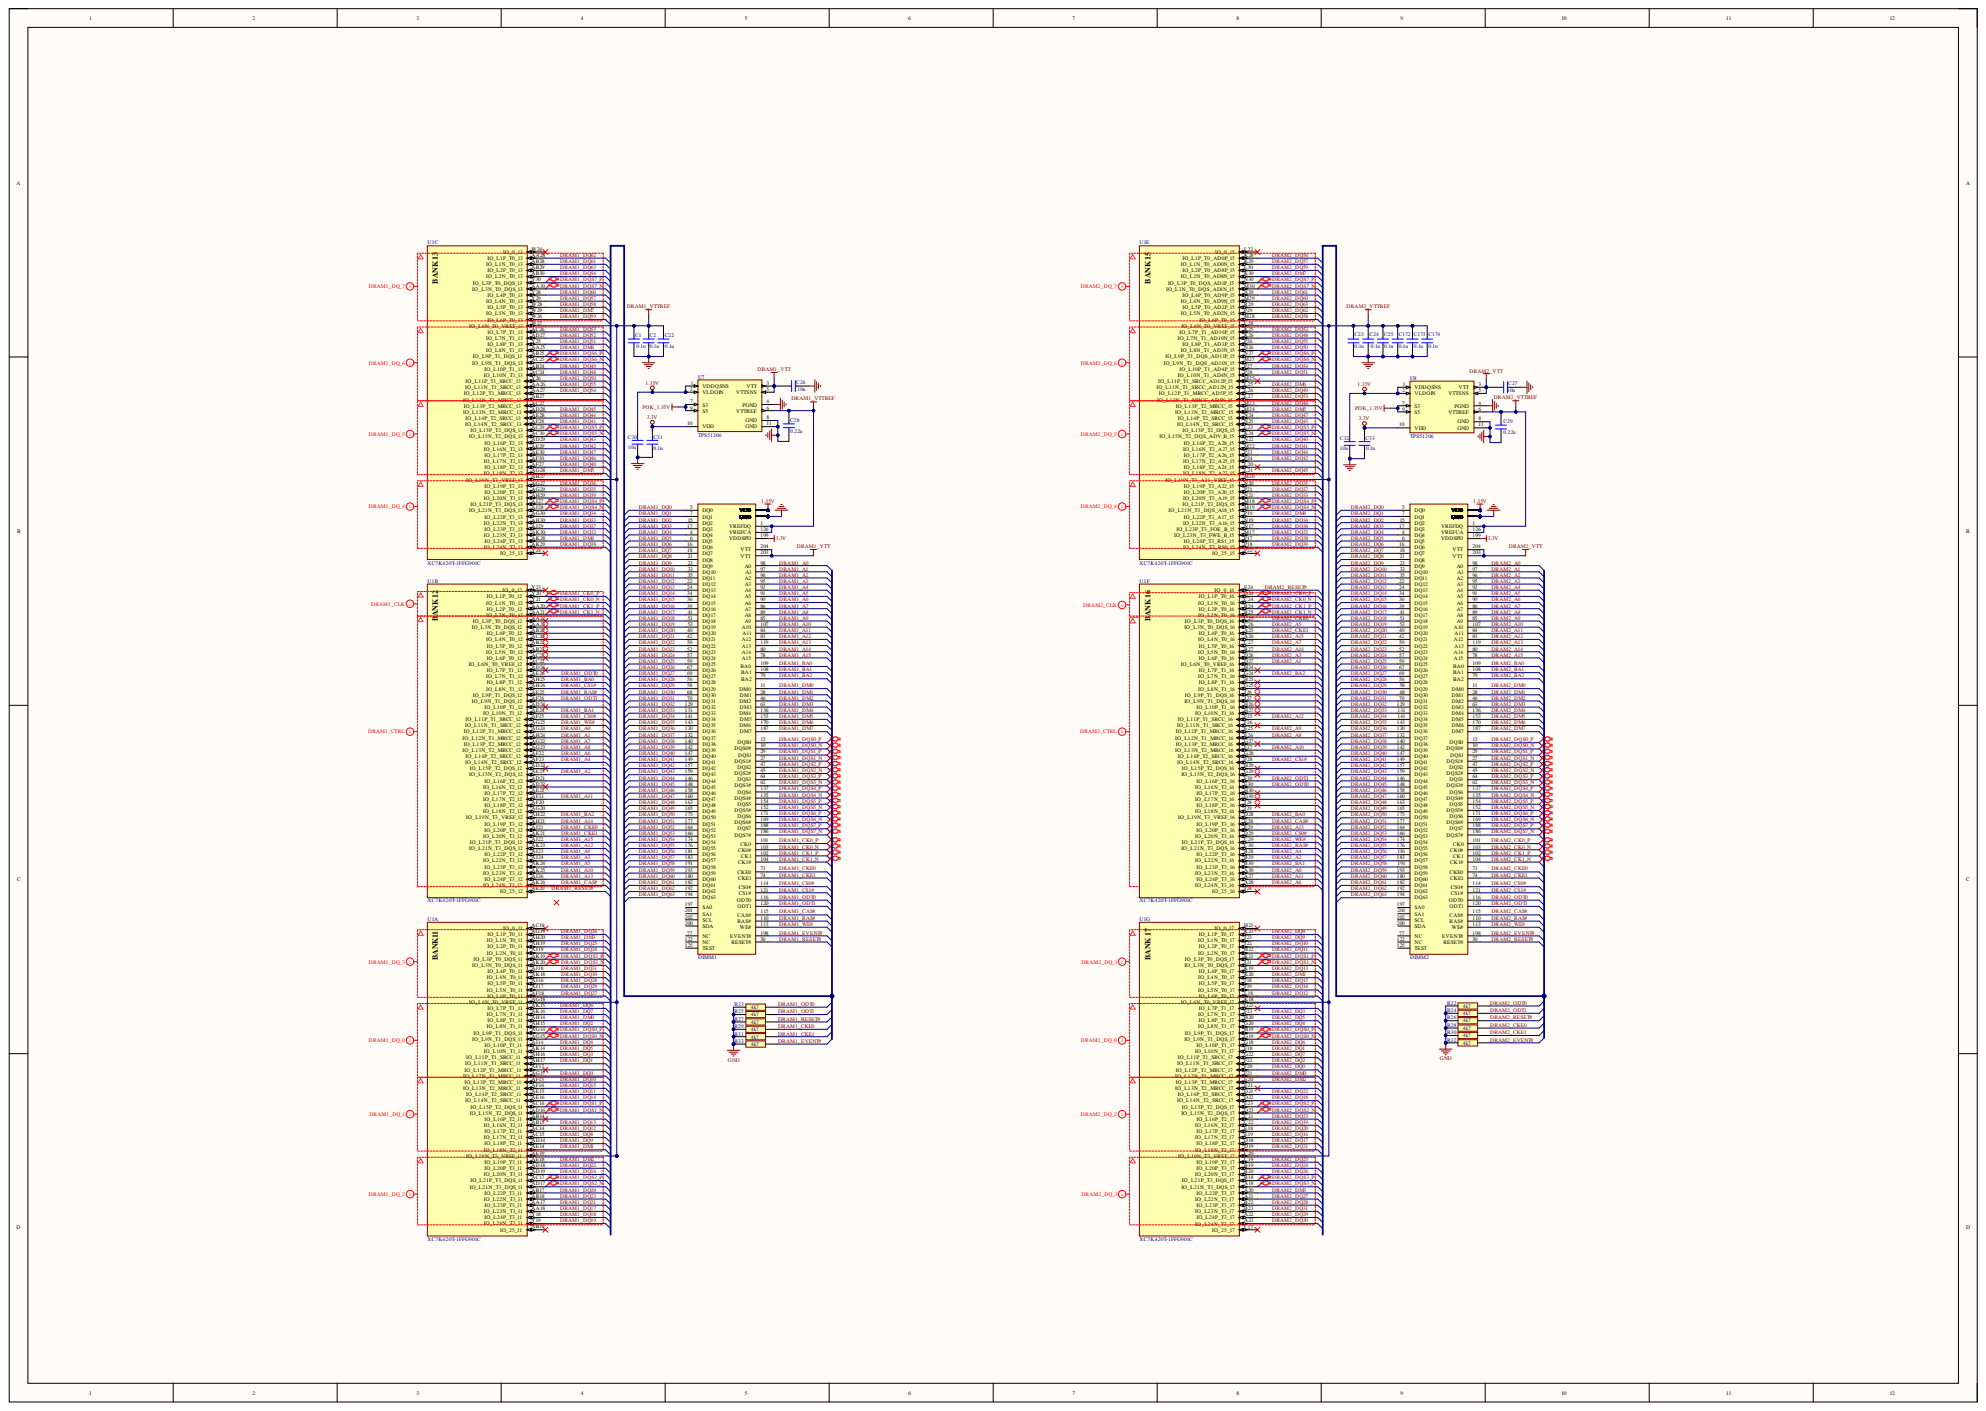
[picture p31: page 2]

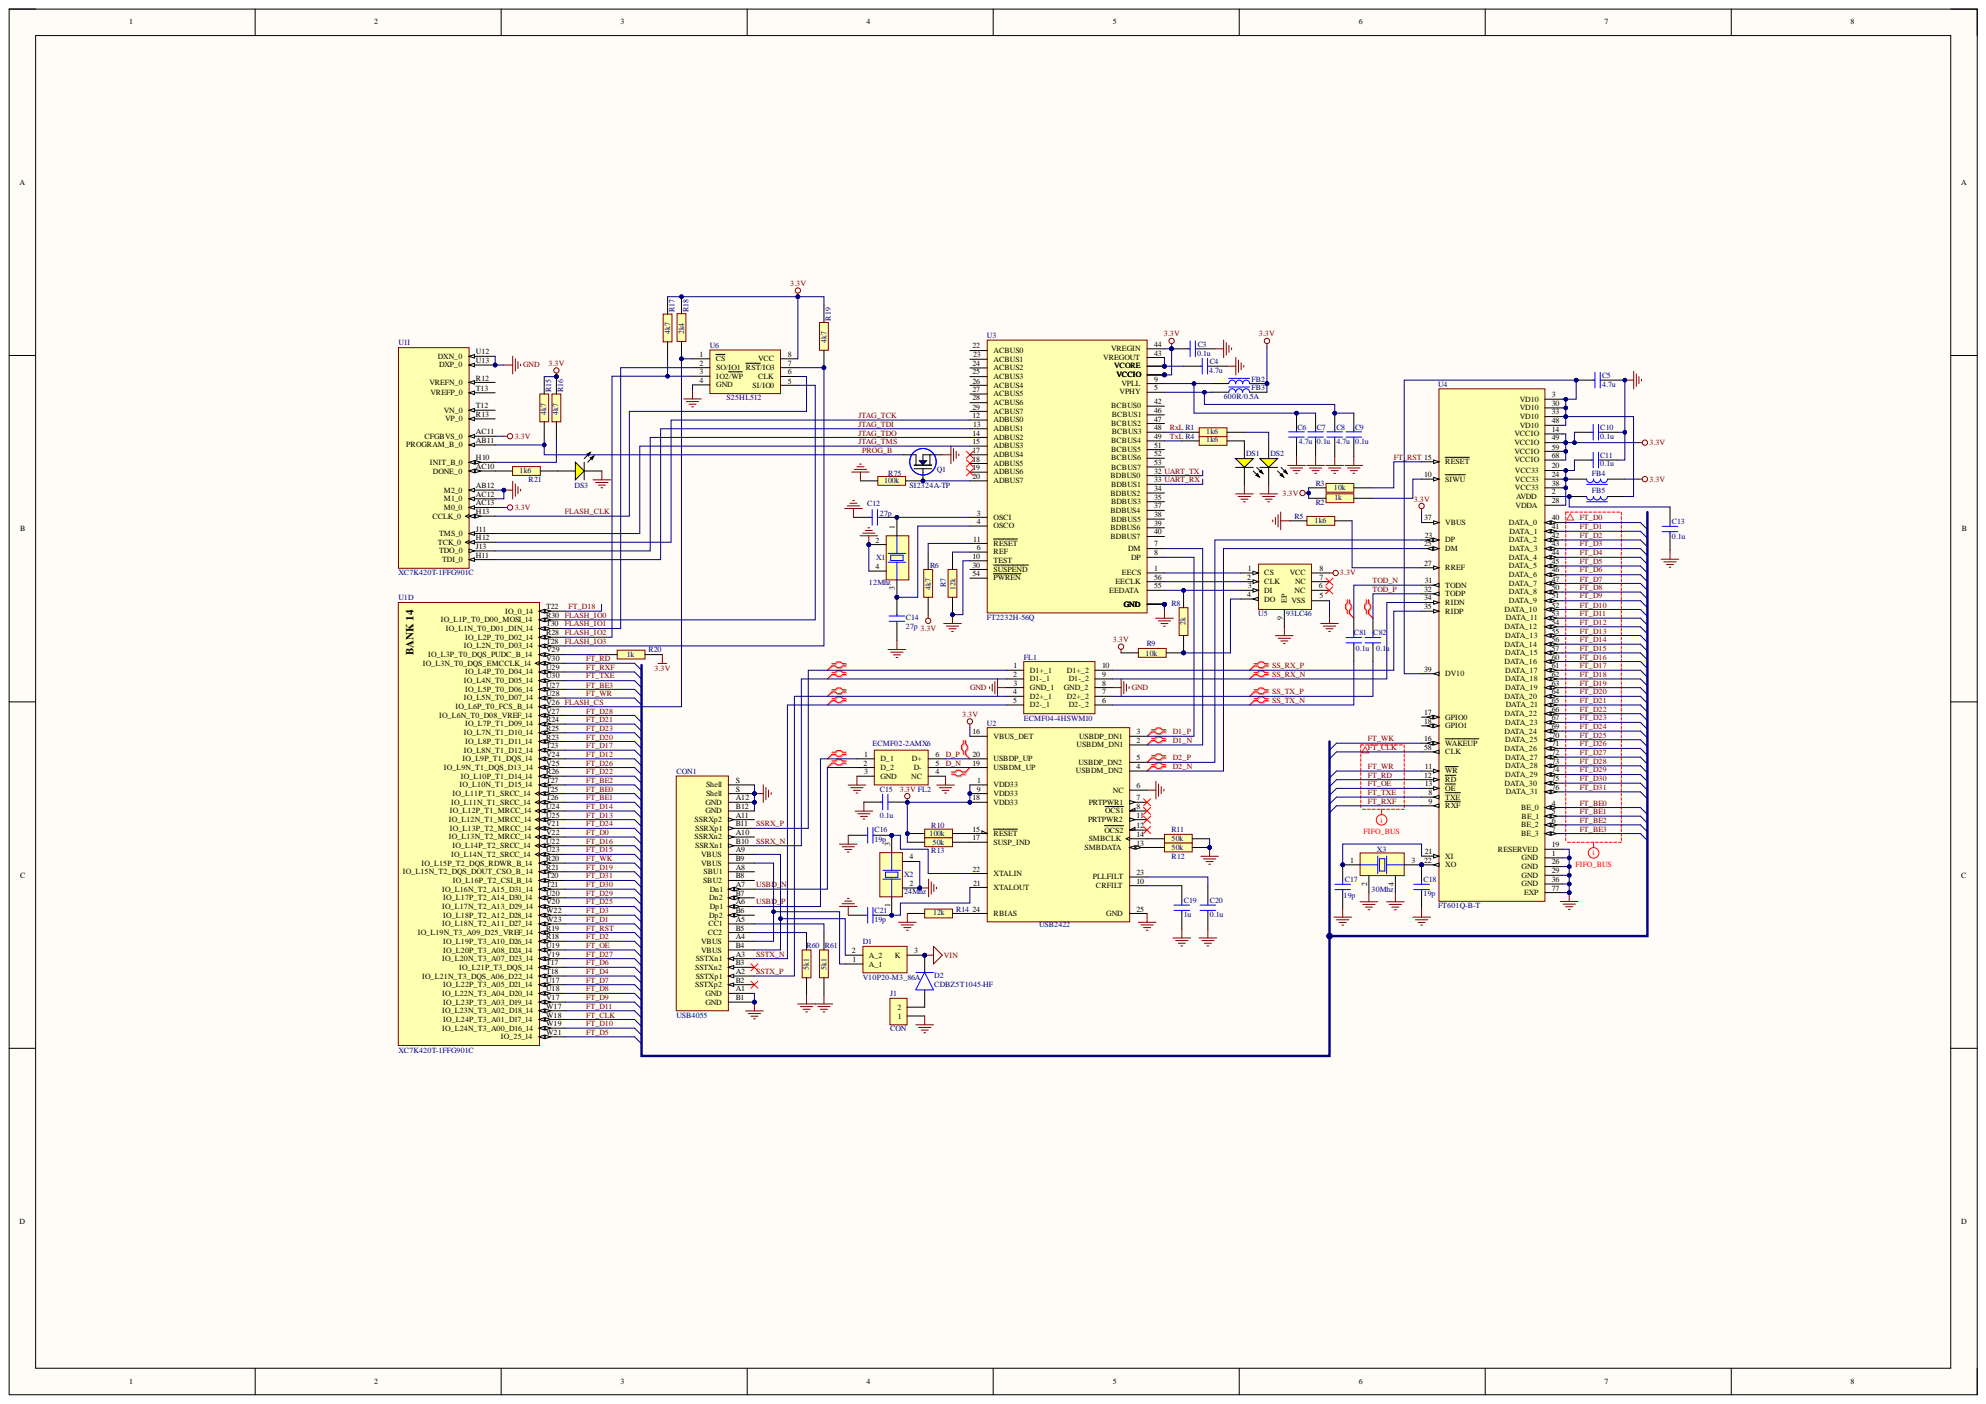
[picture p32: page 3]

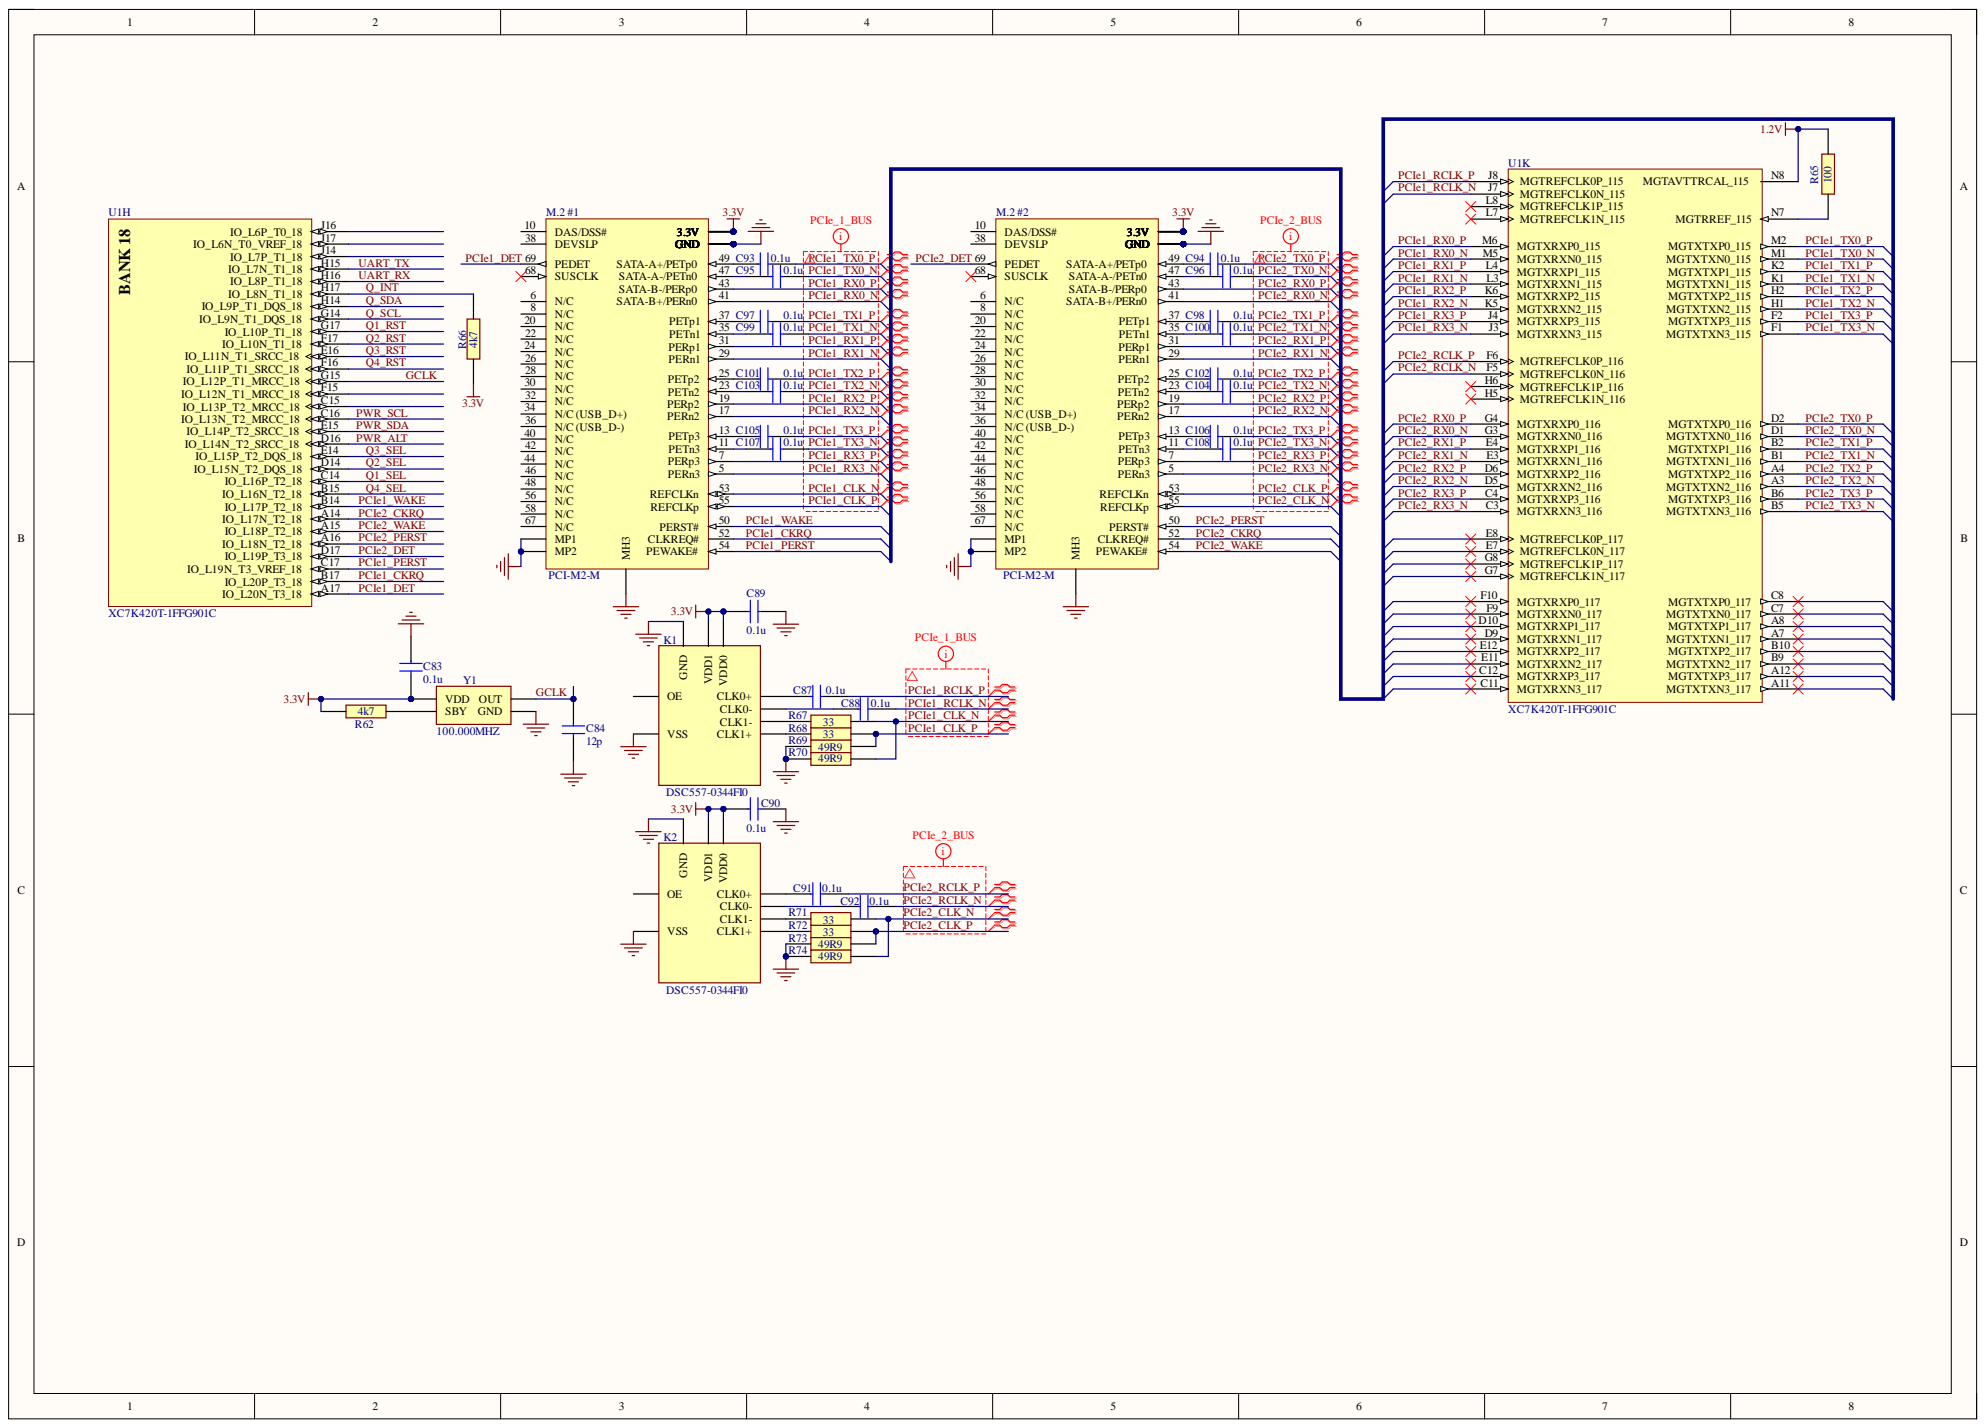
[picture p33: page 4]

R 6 8 | 3 3 | P C I e 1 _ C L K_P
R 6 9 R 7 0 | 4 9 R 9

R 7 1 | 3 3 | | P C I e 2 _ C L K_N
R 7 2 | 3 3 | | | P C I e 2 _ C L K_P
R 7 3 | 4 9 R 9
R 7 4 | 4 9 R 9

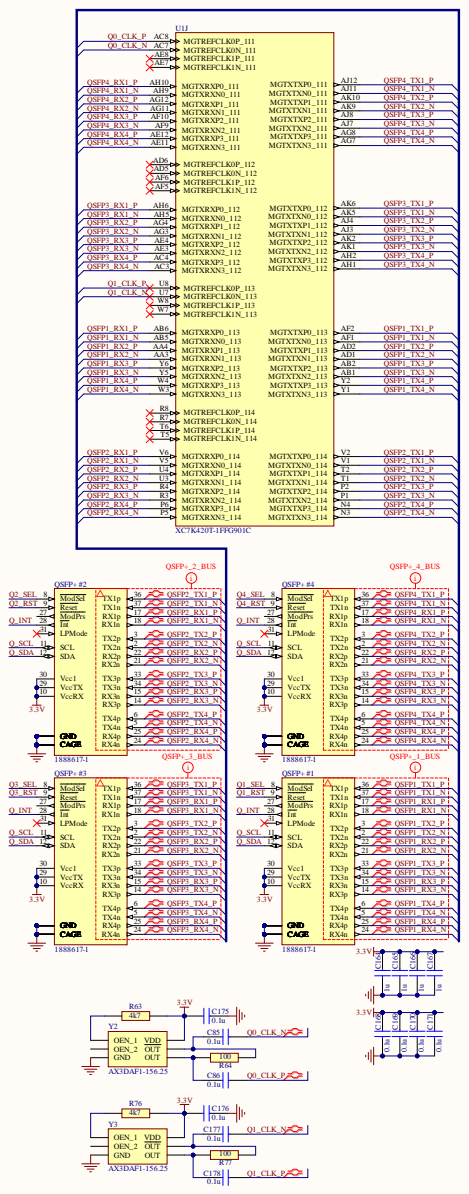
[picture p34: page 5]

QSFP4_RX2_P QSFP4_RX2_N | MGTXRXN3_111 AE11 MGTXRXP3_111 AE12 MGTXRXN2_111 AF9 MGTXRXP2_111 AF10 MGTXRXN1_111 AG11 MGTXRXP1_111 AG12 MGTXRXN0_111 AH9 MGTXRXP0_111 AH10 | QSFP4_TX2_P QSFP4_TX2_N
QSFP4_RX1_N | QSFP4_TX1_N

QSFP4_RX3_P | | QSFP4_TX3_P
QSFP4_RX3_N | | QSFP4_TX3_N
QSFP4_RX4_P | | QSFP4_TX4_P
QSFP4_RX4_N | | QSFP4_TX4_N

QSFP3_RX1_P | MGTREFCLK1N_112 AF5 MGTREFCLK1P_112 AF6 MGTREFCLK0N_112 AD5 MGTREFCLK0P_112 AD6 | QSFP3_TX1_P

QSFP3_RX2_P | MGTXRXN3_112 AC3 MGTXRXP3_112 AC4 MGTXRXN2_112 AE3 MGTXRXP2_112 AE4 MGTXRXN1_112 AG3 MGTXRXP1_112 AG4 MGTXRXN0_112 AH5 MGTXRXP0_112 AH6 | QSFP3_TX2_P
QSFP3_RX1_N | | QSFP3_TX1_N

QSFP3_RX2_N | | QSFP3_TX2_N
QSFP3_RX3_P | | QSFP3_TX3_P
QSFP3_RX3_N QSFP3_RX4_P | QSFP3_TX3_N QSFP3_TX4_P

QSFP3_RX4_N Q1_CLK_P | QSFP3_TX4_N QSFP1_TX1_P

QSFP1_RX2_P | MGTXRXN3_113 W3 MGTXRXP3_113 W4 MGTXRXN2_113 Y5 MGTXRXP2_113 Y6 MGTXRXN1_113 AA3 MGTXRXP1_113 AA4 MGTXRXN0_113 AB5 MGTXRXP0_113 AB6 | QSFP1_TX2_P
QSFP1_RX1_N | | QSFP1_TX1_N

QSFP1_RX2_N | | QSFP1_TX2_N
QSFP1_RX3_P | | QSFP1_TX3_P
QSFP1_RX3_N | | QSFP1_TX3_N
QSFP1_RX4_P | | QSFP1_TX4_P
QSFP1_RX4_N | | QSFP1_TX4_N

QSFP2_RX1_P | MGTREFCLK1N_114 T5 MGTREFCLK1P_114 T6 MGTREFCLK0N_114 R7 MGTREFCLK0P_114 R8 | QSFP2_TX1_P

QSFP2_RX2_P | MGTXRXN3_114 P5 MGTXRXP3_114 P6 MGTXRXN2_114 R3 MGTXRXP2_114 R4 MGTXRXN1_114 U3 MGTXRXP1_114 U4 MGTXRXN0_114 V5 MGTXRXP0_114 V6 | QSFP2_TX2_P
QSFP2_RX1_N | | QSFP2_TX1_N

QSFP2_RX2_N | | QSFP2_TX2_N
QSFP2_RX3_P | | QSFP2_TX3_P
QSFP2_RX3_N | | QSFP2_TX3_N
QSFP2_RX4_P | | QSFP2_TX4_P
QSFP2_RX4_N | | QSFP2_TX4_N

QSFP2_RX2_N | VccTX 29 Vcc1 30 | QSFP4_RX2_N

QSFP3_RX2_N | VccTX 29 Vcc1 30 | QSFP1_RX2_N
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
